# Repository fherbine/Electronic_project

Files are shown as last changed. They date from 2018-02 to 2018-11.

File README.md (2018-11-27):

# Electronic project at 42 - CompassIO project

banner

## Electronic project from 42 school.
During 7 months we had to make a connected compass from scrath.

 - It began in February after we passed a test to be able to register to the Electronic project at school.

 - First we had to write specifications about our project during a month: including user manual, the description of our project and a first Bill of Material. You can access to these specifications [here](https://github.com/fherbine/Electronic_project/blob/master/vomnes_IBoussole_Cahier_des_Charges.pdf).

 - Then we had to make a proof of concept, from march to June. This step has shown our capability to build a final prototype for our project.

POC

- Finally we built our prototype !

Proto

PCB pcb

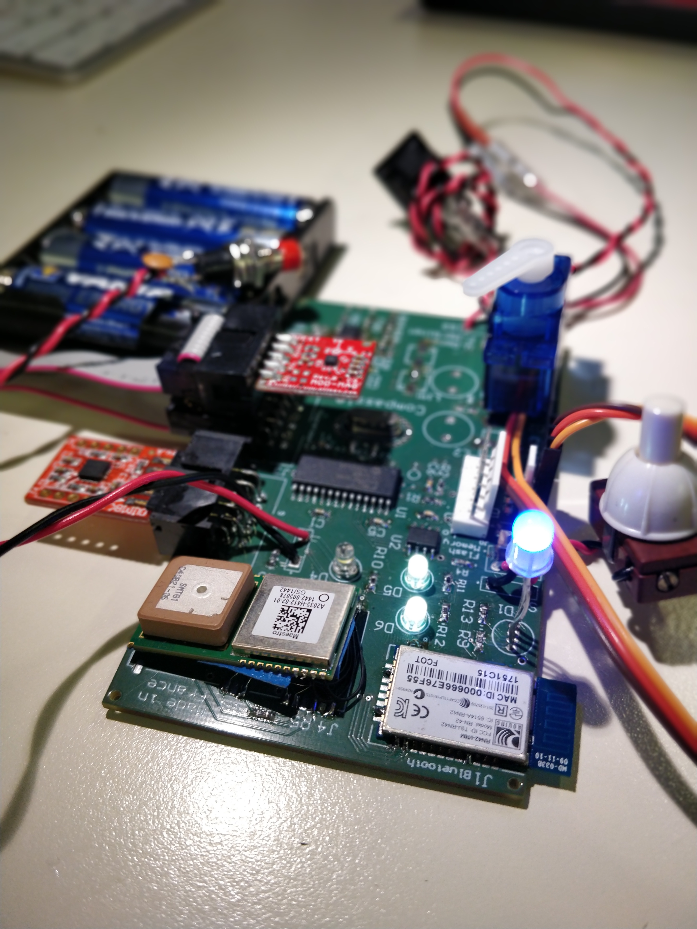
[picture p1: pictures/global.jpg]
Global global


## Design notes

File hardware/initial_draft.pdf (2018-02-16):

Initial schematic draft of the project

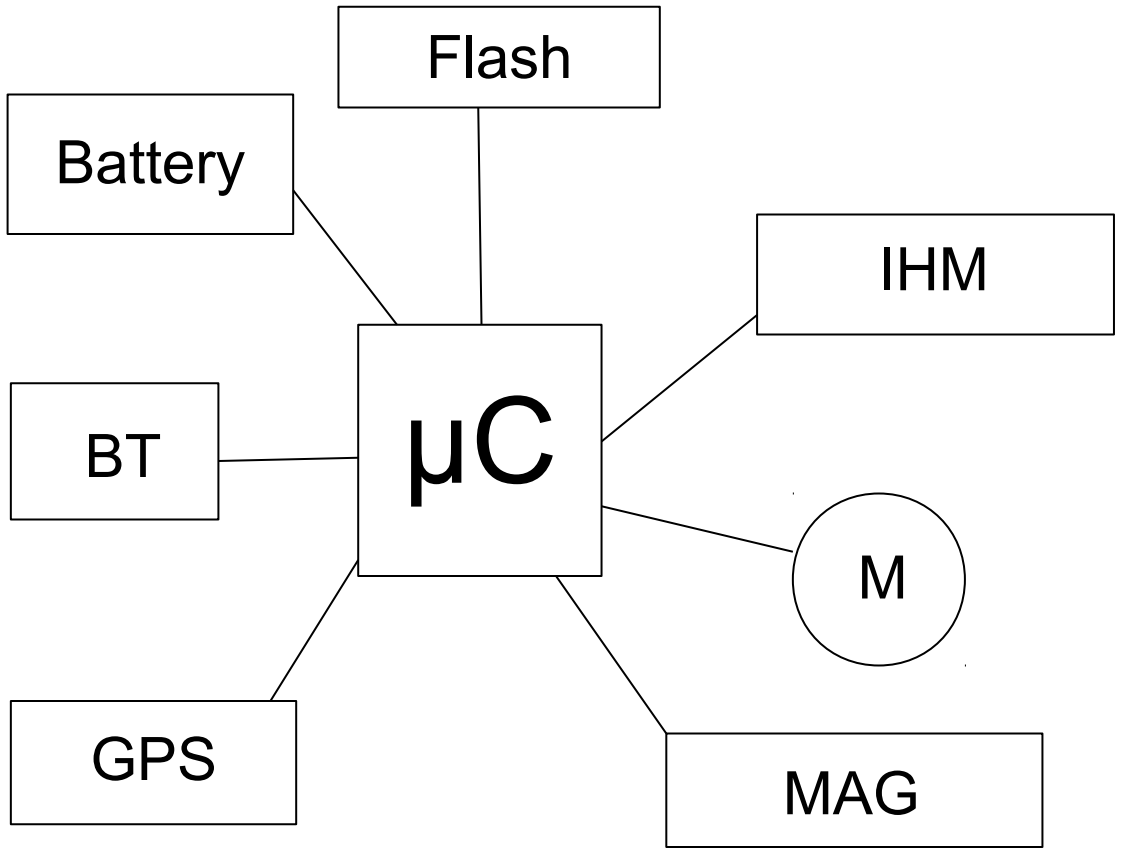
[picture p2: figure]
Flash; Battery; IHM; GPS; MAG

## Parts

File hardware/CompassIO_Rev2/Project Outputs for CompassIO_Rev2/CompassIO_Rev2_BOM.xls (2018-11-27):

Comment | Description | Designator | Fabricant | Fournisseur | Quantity | RefFabricant | RefFournisseur
5-10V | 4xAA | BT1 |  |  | 1
0.1uF | Capacitor | C1, C6, C12 | AVX | Farnell | 3 | 0603YC104KAZ2A | 7569556
0.1µF | Capacitor | C2, C3, C4 | AVX | Farnell | 3 | 0603YC104KAZ2A | 7569556
10µF | Capacitor | C5 | MURATA | Farnell | 1 | GRM188R60J106KE47D | 2494230
100nF | Capacitor | C7 | AVX | Farnell | 1 | 0603YC104KAZ2A | 7569556
22uF | Capacitor | C8 | MURATA | Farnell | 1 | GRM188R61A226ME15D | 2666496
8.2nF | Capacitor | C9 | MULTICOMP | Farnell | 1 | MC0603B822K500CT | 1759101
1.2nF | Capacitor | C10 | Walsin | Farnell | 1 | 0603B122K500CT | 2524822
25pF | Capacitor | C11 | WALSIN | Farnell | 1 | 0603N250J500CT | 2524884
47uF | Capacitor | C13, C14 | MURATA | Farnell | 2 | GRM21BR60J476ME15L | 2362109
LED3 | Typical BLUE SiC LED | D1, D2, D3 | ROHM | Farnell | 3 | SMLE13WBC8W1 | 2762565
LED0 | Typical INFRARED GaAs LED | D4, D6 | KINGBRIGHT | Farnell | 2 | KPH-1608SGC, KPT-1608LVVBC-D | 2426215, 2610410
LED0 | Typical INFRARED GaAs LED | D5 | KINGBRIGHT | Farnell | 1 | KP-2012EC | 8529949
SS24FL | Schottky Rectifier | D7 | ON SEMICONDUCTOR | Farnell | 1 | SS24FL | 2822566
Program / Debug | Program / Debug | J0 | Molex | Farnell | 1 | 22-27-2061 | 9731172
jumper | Jumper | J1, J7 |  |  | 2
RN42 | Bluetooth Module | J2 | Microchip | Farnell | 1 | RN42-I/RM | 2143310
DEBUG1 | Debug interface | J3, J6 |  |  | 2
MAG3110 Breakout | MAG3110 Breakout | J4 | AMP - TE Connectvity | Farnell | 1 | 5103310-1 | 2452436
A2035-H | GPS Module | J5 | MAESTRO WIRELESS SOLUTIONS | Farnell | 1 | A2035H | 2281693
10uH | Inductor | L1 | BOURNS | Farnell | 1 | SRN8040-100M | 2061669
SG90 | Servo motor | M1 | Molex | Farnell | 1 | 22-27-2031 | 9731156
10K | Resistor | R1, R2, R4, R5, R8 | PANASONIC ELECTRONIC COMPONENTS | Farnell | 5 | ERA3ARW103V | 1688472
1K | Resistor | R3 | PANASONIC ELECTRONIC COMPONENTS | Farnell | 1 | ERA3ARB102V | 1717570
2.4K | Resistor | R6, R7 | VISHAY | Farnell | 2 | CRCW06032K40FKEA | 1469766
100 | Resistor | R9, R10, R11, R12, R13 | VISHAY | Farnell | 5 | CRCW0603100RJNEA | 2616742
330 | Resistor | R14 | PANASONIC ELECTRONIC COMPONENTS | Farnell | 1 | ERJ3GEYJ331V | 2059588
174K | Resistor | R15 | VISHAY | Farnell | 1 | CRCW0603174KFKEA | 2138522
133K | Resistor | R16 | MULTICOMP | Farnell | 1 | MCWR06X1333FTL | 2694713
44.2K | Resistor | R17 | VISHAY | Farnell | 1 | CRCW060344K2FKEA | 2138466
10.2K | Resistor | R18 | PANASONIC ELECTRONIC COMPONENTS | Farnell | 1 | ERJ3EKF1022V | 2059407
3.24K | Resistor | R19 | VISHAY | Farnell | 1 | CRCW06033K24FKEA | 1652877
SW-PB | Switch | S1, S2 | ALCOSWITCH - TE CONNECTIVITY | Farnell | 2 | 1437566-3 | 2468741
SW-SPST | Single-Pole, Single-Throw Switch | S3, S4 | Arcolectric | Farnell | 2 | H8600VBAAA | 151133
PIC32MX250F128B | Microcontrolleur | U1 | Microchip | Farnell | 1 | PIC32MX250F128B-I/SO | 2097772
LE25U40CMD | Flash memory | U2 | On Semiconductor | Farnell | 1 | LE25U40CMDTWG | 2627898
TPS54231D | Buck SD 3.3V | U3 | Texas Instruments | Farnell | 1 | TPS54231D | 2854681

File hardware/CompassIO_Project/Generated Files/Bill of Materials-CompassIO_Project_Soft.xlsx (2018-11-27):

Comment | Description | Designator | Fabricant | Footprint | Fournisseur | Library Reference | Quantity | RefFabricant | RefFournisseur
SG90 | Servo motor | MP1 | MCmall |  | Amazon | SG90 | 1 | SG90 180 Mini Servo
MOSFET-2N7002 | N-Channel MOSFET | Q1 | ON SEMICONDUCTOR | E3 | Farnell | MOSFET-N | 1 | 2N7002 | 2323152
RN42 | Bluetooth Module | U1 | Microchip |  | Farnell | RN42 | 1 | RN42-I/RM | 2143310
MOD-MPU9150 | 9-Axis | U2 | Olimex - InvenSense |  | Olimex | MOD-MPU9150 | 1 | MOD-MPU9150 | MOD-MPU9150
A2035-H | GPS Module | U3 | MAESTRO WIRELESS SOLUTIONS |  | Farnell | A2035-H | 1 | A2035H | 2281693
LE25U40CMD | Flash memory | U4 | On Semiconductor |  | Farnell | LE25U40CMD | 1 | LE25U40CMDTWG | 2627898

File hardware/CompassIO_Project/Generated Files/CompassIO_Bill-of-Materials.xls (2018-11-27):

BILL OF MATERIALS
Projet : |  | CompassIO.PrjPcb |  |  | Toutes résistances 1% sauf indication contraire
Date creation : |  | 26/04/2018 |  |  | Tous condensateurs X5R 6.3V minimum sauf indication contraire
Date impression : |  | 2018-04-26 | 20:03:22 |  | Condensateurs <= 100nF : C0G ou NP0 préférables
Quantity | LogicalDesignator | Comment | Footprint | Description | Fabricant | RefFabricant | Fournisseur | RefFournisseur
2 | D1, D3 | Green LED | LED-0 | Connection Status, Blinky LED
1 | D2 | Red LED | LED-0 | Activity
2 | R1, R2 | 470 | AXIAL-0.3 | Resistor
1 | R3 | 10K | AXIAL-0.3 | Resistor
1 | R4 | 1K | AXIAL-0.3 | Resistor
2 | R5, R6 | 5K | AXIAL-0.3 | Resistor
3 | S1, S3, S5 | Single-Pole, Single-Throw Switch | SPST-2 | Button Discovery, GPS Firmware, Disable write protect
3 | S2, S4, S6 | Switch | SPST-2 | Factory reset, Reset, Suspend communication
1 | U1 | RN42 |  | Bluetooth Module | Microchip | RN42-I/RM | Farnell | 2143310
1 | U2 | MOD-MPU9150 |  | 9-Axis | Olimex - InvenSense | MOD-MPU9150 | Olimex | MOD-MPU9150
1 | U3 | A2035-H |  | GPS Module | MAESTRO WIRELESS SOLUTIONS | A2035H | Farnell | 2281693
1 | U4 | LE25U40CMD |  | Flash memory | On Semiconductor | LE25U40CMDTWG | Farnell | 2627898

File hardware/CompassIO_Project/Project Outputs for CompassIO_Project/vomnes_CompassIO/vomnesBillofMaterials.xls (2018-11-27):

BILL OF MATERIALS
Projet : |  | CompassIO_Project.PrjPcb
Date creation : |  | 28/01/2015 | 17:45:48
Date impression : |  | 2018-07-02 | 19:32:13
Quantity | LogicalDesignator | Comment | Footprint | Description | Fabricant | RefFabricant | Fournisseur | RefFournisseur | Precision | #Column Name Error:Notes
2 | C11, C12 | Cin | WE-865080542005 | Polarized Capacitor (Radial) | WURTH ELEKTRONIK | 865080542005 | Farnell | 2466314 | Cap Pol1
1 | C16 | Cout | SMT-HA-V-D | Polarized Capacitor (Radial) | PANASONIC ELECTRONIC COMPONENTS | EEEHA1A101WP | Farnell | 1973294 | Cap Pol1
1 | D1 | L-154A4SUREQBFZGEW | L-154A4SUREQBFZGEW | LED RGB | Kingbright | L-154A4SUREQBFZGEW | Farnell | 2290375 | L-154A4SUREQBFZGEW
1 | D2 | MBRS130LT3 | SMB-403A-03-J | Schottky Rectifier | ON SEMICONDUCTOR | MBRS130LT3G | Farnell | 9556931 | Diode 10TQ035
1 | D3 | B240A | SMA-B2XX/A | Schottky Rectifier | DIODES INC. | B240A-13-F | Farnell | 1843669 | Diode 10TQ035
3 | D4, D5, D6 | LED3 | LED2.5 | Typical BLUE SiC LED | MULTICOMP | MCL034SWC-WH1 | Farnell | 1581176 | LED3
1 | J0 | Program / Debug | C-Grid III X6 | Program / Debug | Molex | 90120-0126 | Farnell | 2313717 | ICSP
2 | J2, J3 | MOD Connector | UEXT_MALE x10 | UEXT | AMP - TE Connectivy | 5103310-1 | Farnell | 2452436 | MOD-MPU9150
3 | L1, L2, L3 | 10uH | RLB Series | Inductor | BOURNS | RLB0712-100KL | Farnell | 2434811 | Inductor
1 | M1 | SG90 Connector | C-Grid III x3 | Servo motor Connector | Molex | 22-27-2031 | Farnell | 9731156 | SG90
1 | Q1 | MOSFET-2N7002 | 2N7002 | N-Channel MOSFET | ON SEMICONDUCTOR | 2N7002 | Farnell | 9845313 | MOSFET-N
1 | Q2 | IRF7807 | SO-8 | MOSFET-8 | INFINEON | IRF7807VTRPBF | Farnell | 2839485 | IRF7807
2 | S3, S4 | SW-SPST | SPST-2 | Single-Pole, Single-Throw Switch | Arcolectric | H8600VBAAA | Farnell | 151133 | SW-SPST
1 | U1 | PIC32MX250F128B | PIC32MX250F128/SO | Microcontrolleur | Microchip | PIC32MX250F128B-I/SO | Farnell | 2097772 | PIC32MX250F128B
1 | U3 | LM3488 | S-PDSO-G8 | SEPIC 5V | Texas Instruments | LM3488MMX/NOPB | Farnell | 2769264 | LM3488
1 | U4 | TPS54231D | R-PDSO-G8 | Buck SD 3.3V | Texas Instruments | TPS54231D | Farnell | 1755637 | TPS54231D
1 | Y1 | 8MHz | 9B-8.000MAAJ-B | Crystal Oscillator | TXC | 9B-8.000MAAJ-B | Farnell | 1842268 | XTAL
2 | J3 | MAG3110 |  | Magnetometer | Olimex | MAG3110 | Olimex | MOD-MAG

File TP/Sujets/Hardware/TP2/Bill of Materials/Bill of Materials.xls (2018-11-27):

BILL OF MATERIALS
Projet : |  | TP2.PrjPcb |  |  | Toutes résistances 1% sauf indication contraire
Date creation : |  | 28/01/2015 | 17:28:42 |  | Tous condensateurs X5R 6.3V minimum sauf indication contraire
Date impression : |  | 2015-01-28 | 17:28:44 |  | Condensateurs <= 100nF : C0G ou NP0 préférables
Quantity | LogicalDesignator | Comment | Footprint | Description | Fabricant | RefFabricant | Fournisseur | RefFournisseur | Precision | #Column Name Error:Notes
7 | C1, C2, C3, C4, C5, C6, C15 | 100nF | CAPC1608N | Capacitor |  |  |  |  | 50V X5R
2 | C7, C8 | 20pF | CAPC1005N | Capacitor |  |  |  |  | 50V X5R
4 | C9, C11, C12, C13 | 10uF | CAPC2012N | Capacitor | TDK | C2012X5R0J106M/1.25 | Farnell | 2309029 | 6,3V X5R
2 | C10, C14 | 1uF | CAPC1608N | Capacitor |  |  |  |  | 6,3V X5R
5 | D1, D1, D1, D1, D4 | Green LED | LED 0805 | Typical INFRARED GaAs LED | KINGBRIGHT | KPT-2012SGC | Farnell | 2099239
2 | D2, D3 | GF1A | SMA/DO-214AC_21 | Default Diode | VISHAY | GF1A-E3/67A | Farnell | 9549560
1 | FB1 | 600r | INDC1608AN | Inductor | Wurth | 742792651 | Farnell | 1635706
1 | J1 | Program / Debug | MOLEX 6P 1.25 CMS |  | Molex | 53398-0671 | Farnell | 1125368
1 | P1 | 12V Main | PHOENIX_1985195 | Header, 2-Pin | PHOENIX CONTACT | PTSA 1.5/2-3,5-Z | Farnell | 1792769
1 | P2 | 12V Battery | PHOENIX_1985195 | Header, 2-Pin | PHOENIX CONTACT | PTSA 1.5/2-3,5-Z | Farnell | 1792769
1 | R1 | 1K | PDB181-K415K-102A2 | Potentiometer | BOURNS | PDB181-K415K-102A2 | Farnell | 1823540
4 | R2 | 330r | RESC1608N | Resistor |  |  |  |  | 1%
1 | R3 | 4.7k | RESC1608N | Resistor |  |  |  |  | 1%
1 | R4 | 470r | RESC1608N | Resistor |  |  |  |  | 1%
1 | U1 | PIC32MX764F128H-I/PT | QFP50P1200X1200X120-64 | PIC32MX764F128H | Microchip | PIC32MX764F128H-I/PT | Farnell | 1971889
1 | U2 | AP1117 | TD03B_N | 1A LDO, 18V input, DPAK | DIODES INC | AP1117D33G-13 | Farnell | 1825285
1 | Y1 | 8MHz | XTAL139X50X45 | Crystal Oscillator | FOX ELECTRONICS | FOXSDLF/080-20 | Farnell | 2063972

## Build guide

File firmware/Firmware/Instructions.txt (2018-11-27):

Le TP se déroule en étapes, à faire valider à chaque fois :

0/ Boot from scratch

Créer un nouveau projet et y ajouter un nouveau .h contenant des typedefs pour :
- u8, u16 et u32
- s8, s16 et s32

1/ Commande de la LED par le bouton (a.k.a Hello World!)

Une pression sur le bouton allume la led
Une autre pression sur le bouton éteint la led

2/ Clignotement de la LED

La led clignotte au rythme d'un changement d'état par seconde (0.5Hz, 1s on/1s off).
Une pression sur le bouton multiplie par deux le rythme de clignotement. Arrivé à 8Hz, une pression sur le bouton remet le rythme à 0.5Hz.

La "séquence" sera donc : 0.5Hz, 1Hz, 2Hz, 4Hz, 8hZ, 0.5Hz, 1Hz, ...

Vous devez utiliser un timer pour régler la vitesse de clignotement

3/ Utilisation des interruptions

Votre code doit maintenant être "non bloquant", votre main loop ne doit contenir qu'un statement: clear watchdog
Le clignotement ainsi que la gestion du bouton doivent être fait dans une ISR.

4/ DIM de la LED (a.k.a pour-les-vrais-qui-en-ont-dans-le-slip-ou-le-string)

Votre code fait toujours la même chose, mais sur un appui long (>2s) la led passe en mode DIM, en 5s son intensité passe de 0 à 100% puis de 100% à 0% (et ainsi de suite)

Pour cela vous coderez en firmware un PWM sur la GPIO qui contrôle la LED.

5/ Ca y est, vous savez tout faire, elle est pas belle la vie ?

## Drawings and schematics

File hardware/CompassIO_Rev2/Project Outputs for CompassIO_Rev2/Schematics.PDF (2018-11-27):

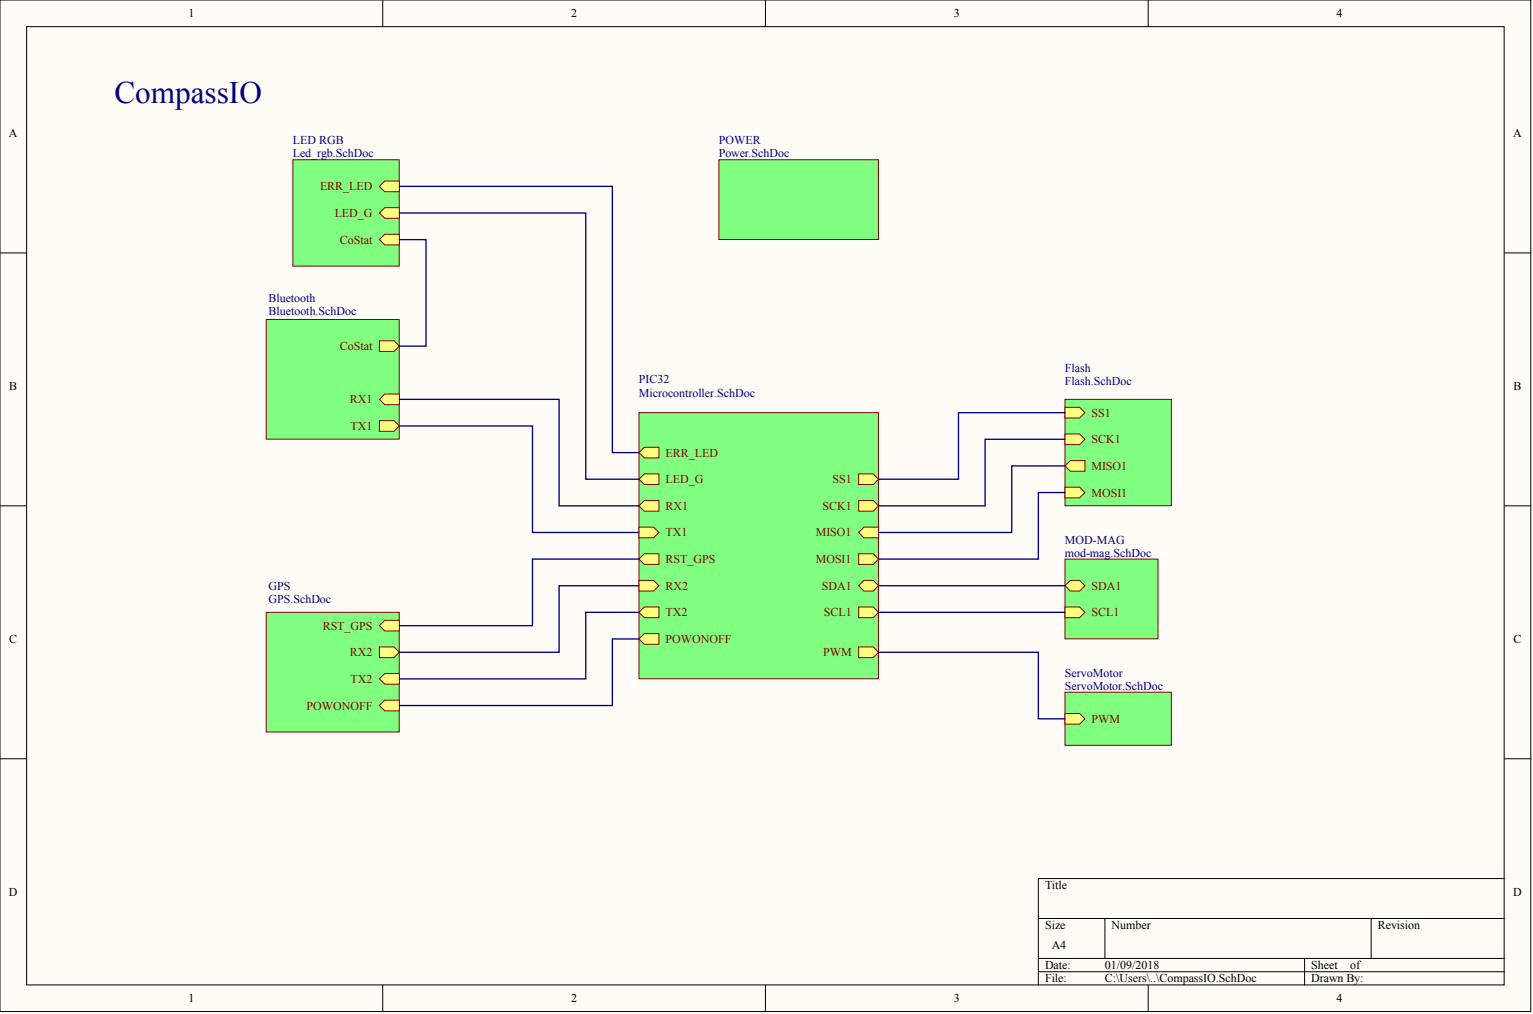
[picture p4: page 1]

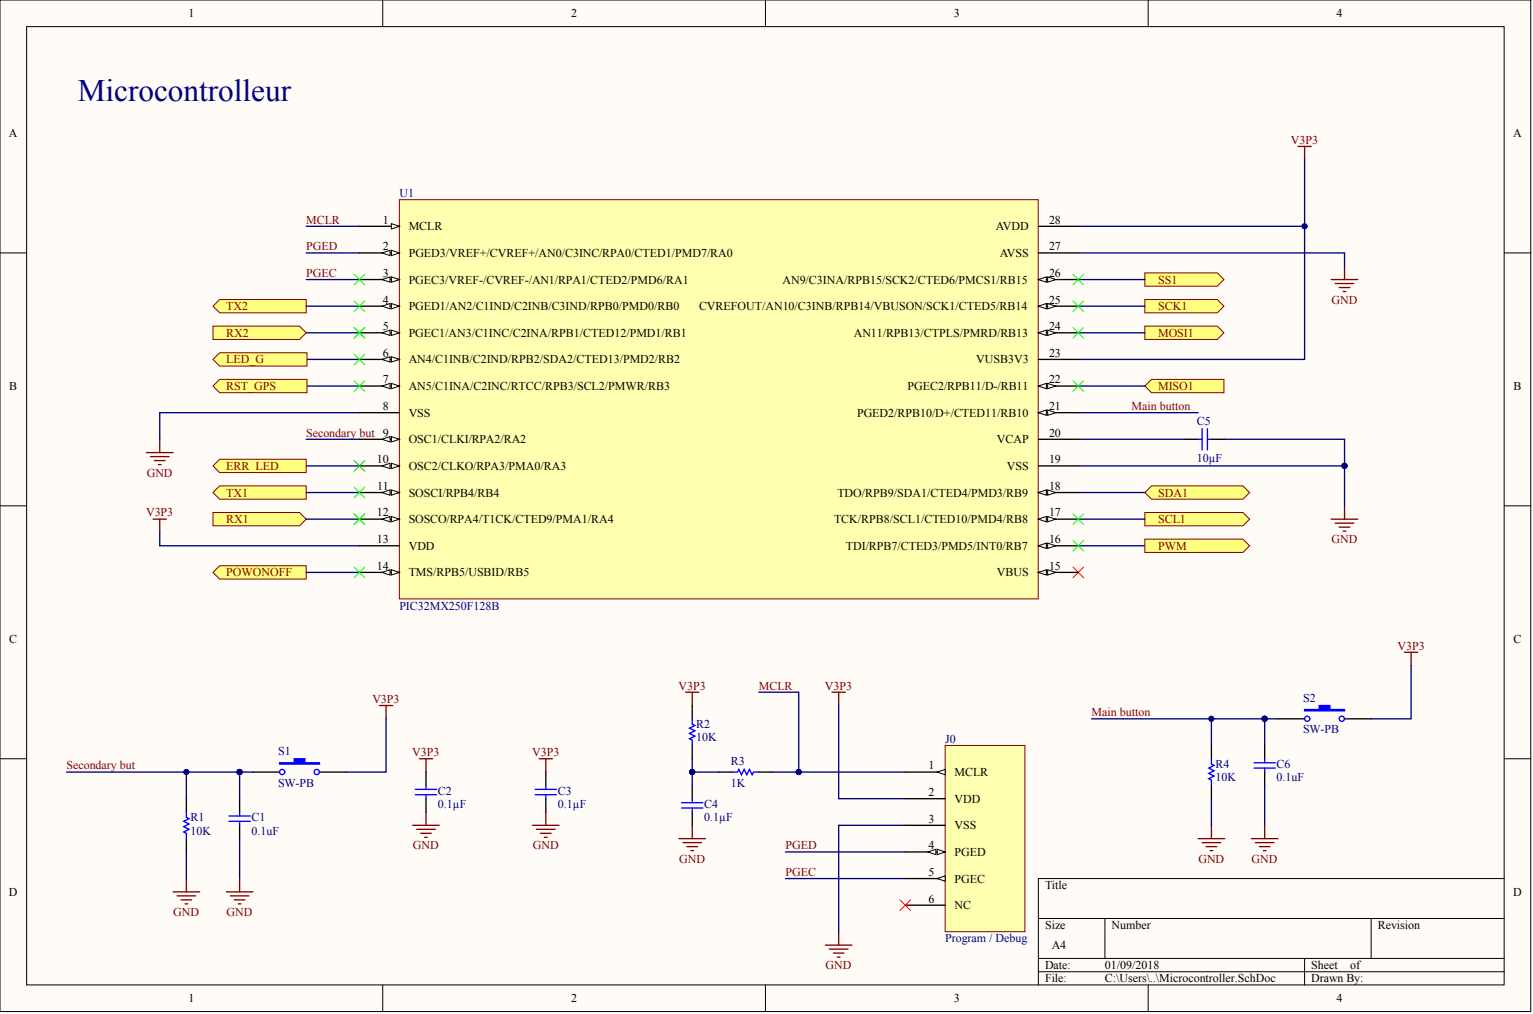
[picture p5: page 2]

Secondary but | | OSC1/CLKI/RPA2/RA2 9

OSC2/CLKO/RPA3/PMA0/RA3 10 | 10µF

SOSCI/RPB4/RB4 11 | | SDA1

VDD 2

VSS 3

PGED 4 PGEC 5

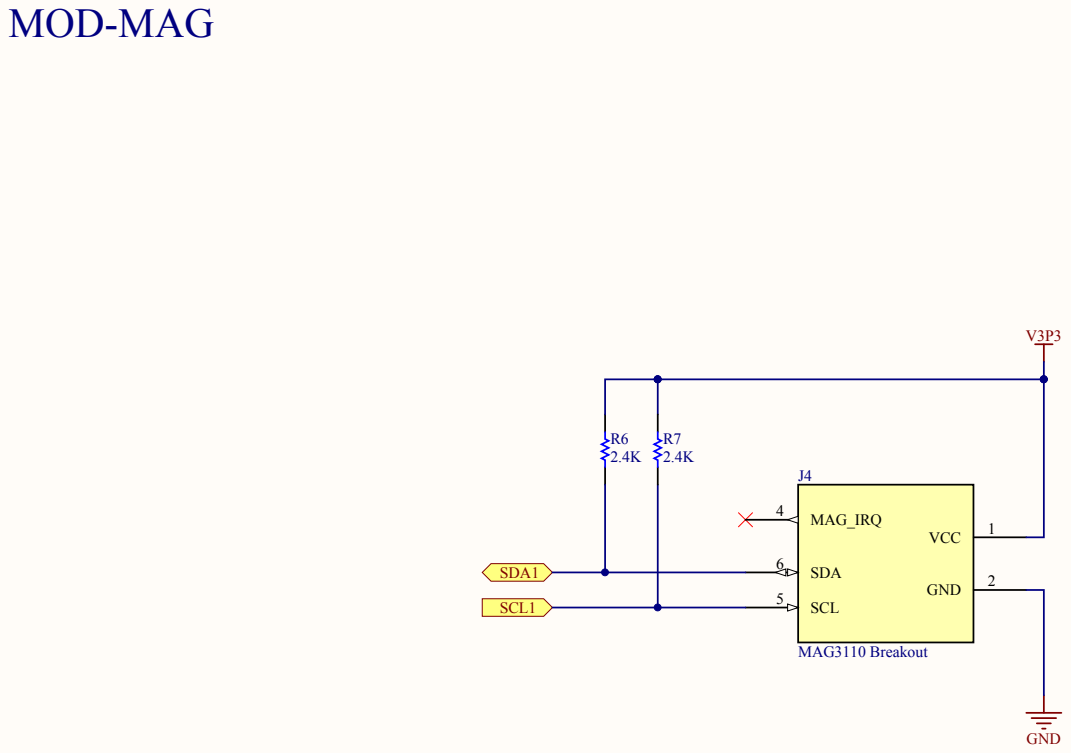
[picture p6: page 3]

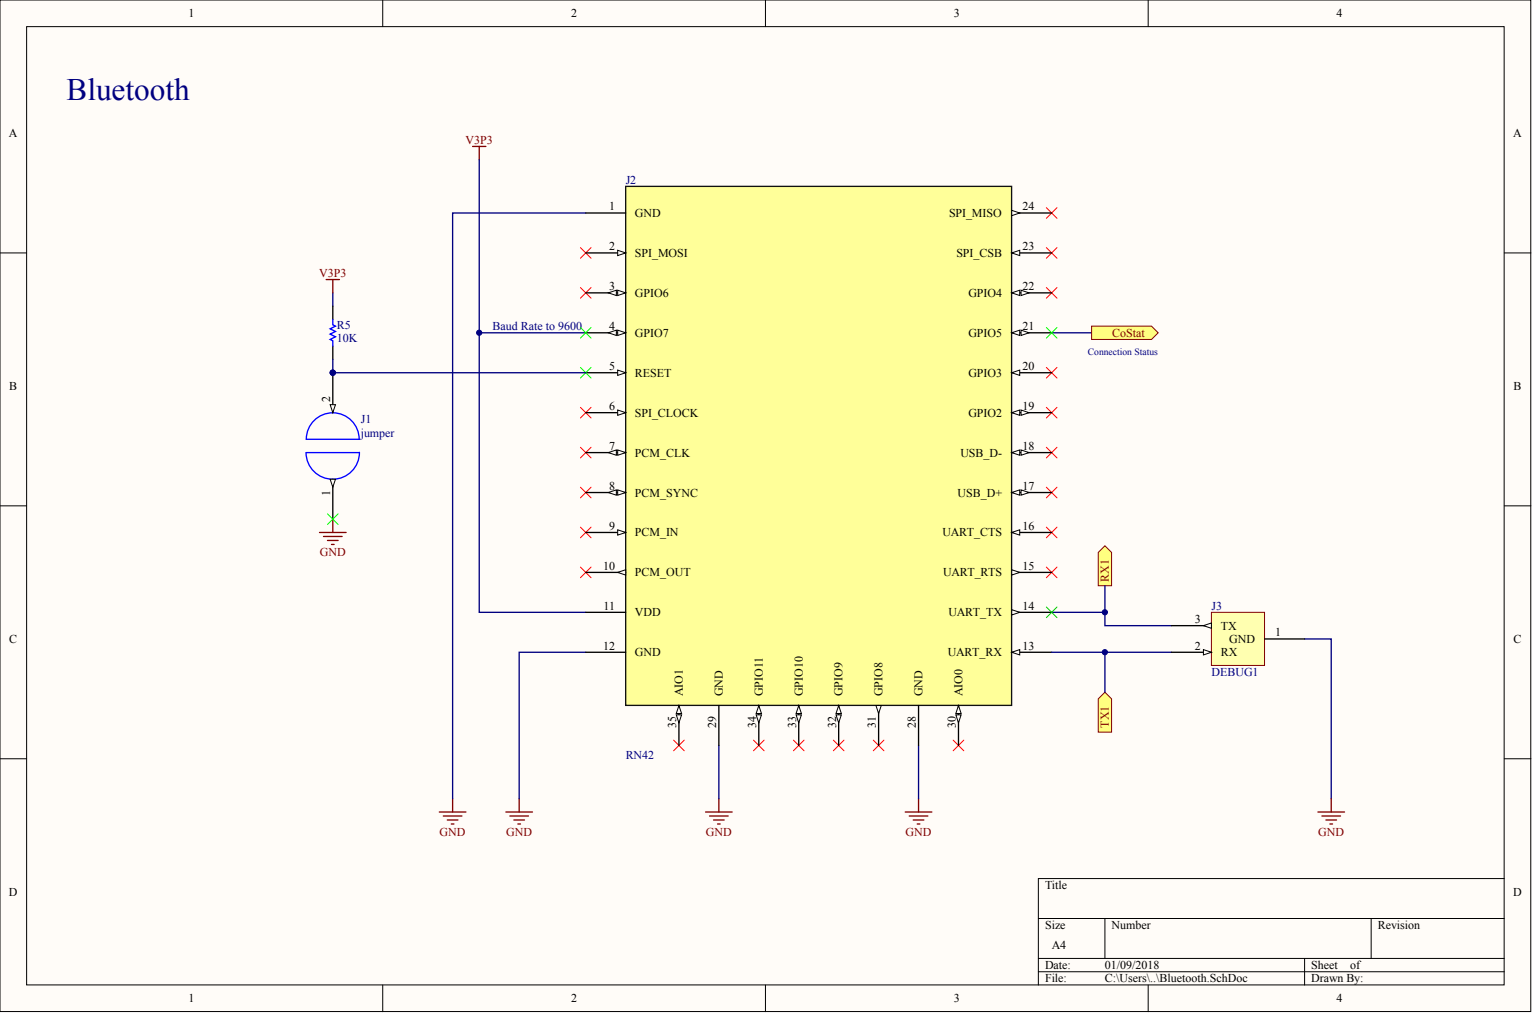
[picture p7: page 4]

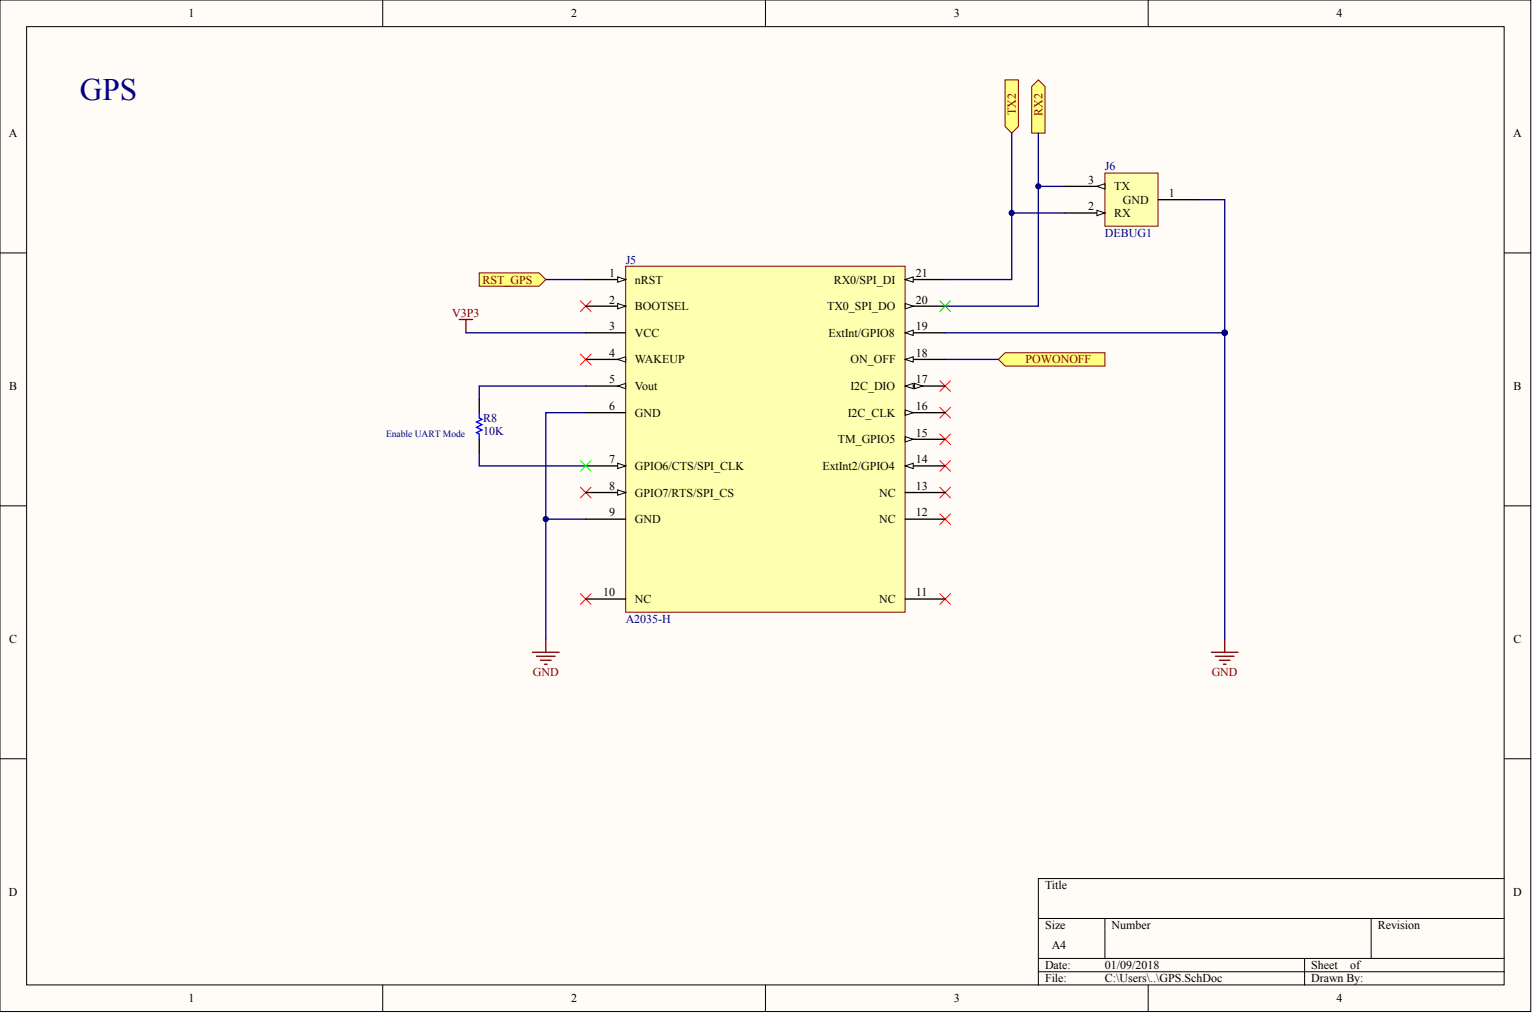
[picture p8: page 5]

GND 6

GPIO7/RTS/SPI_CS 8

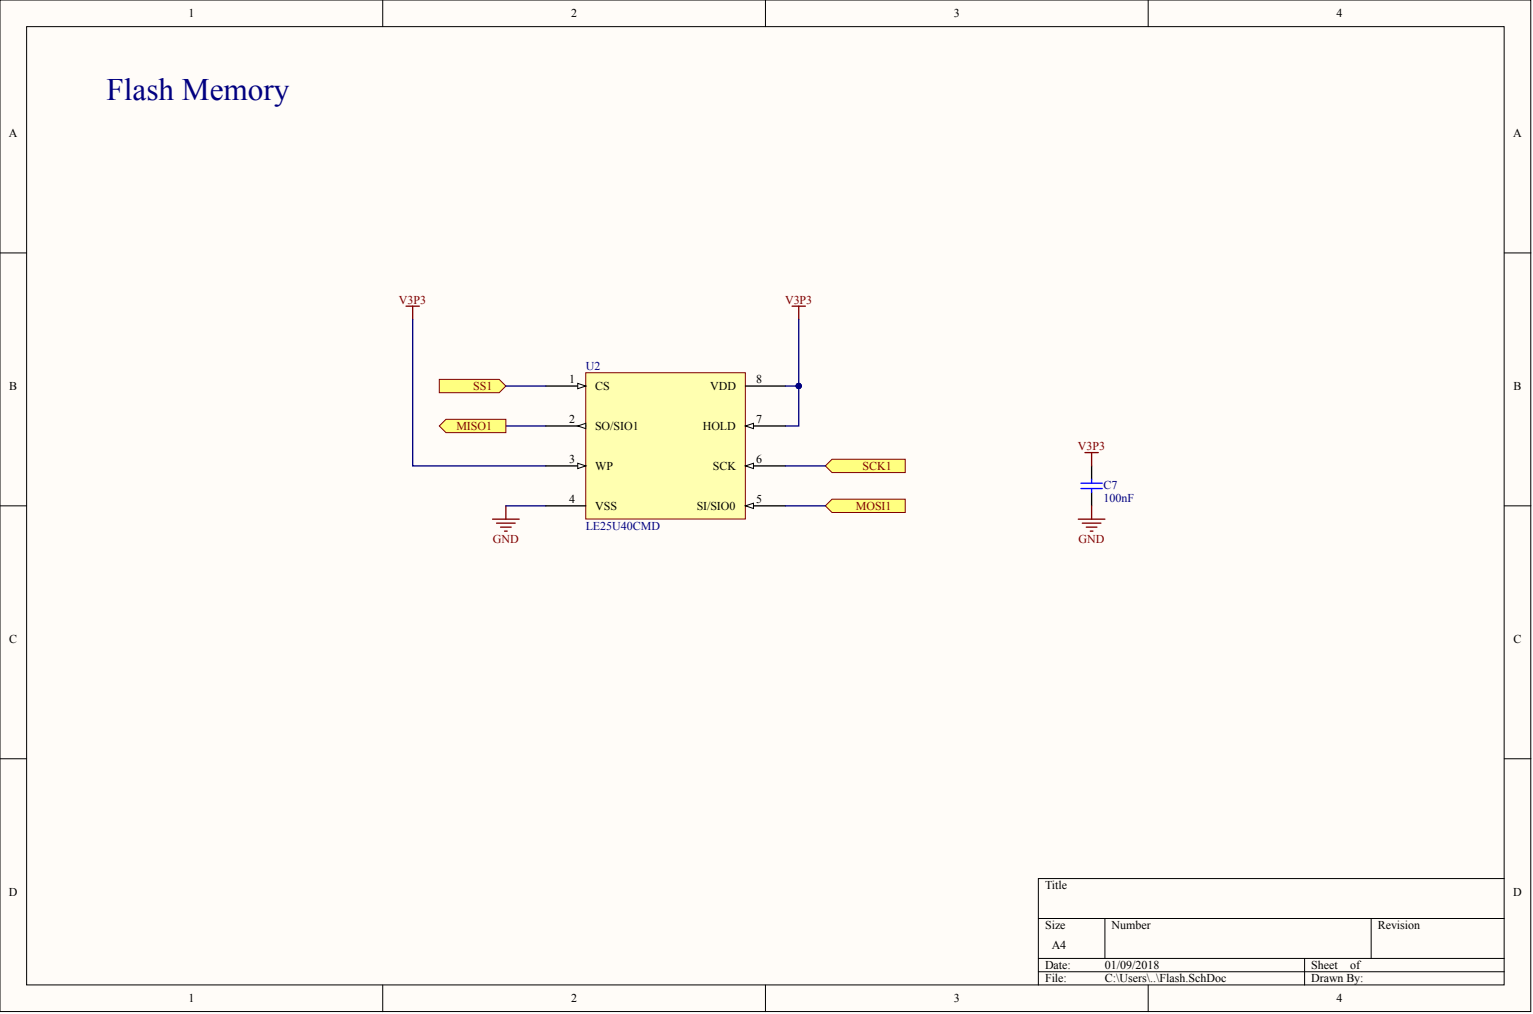
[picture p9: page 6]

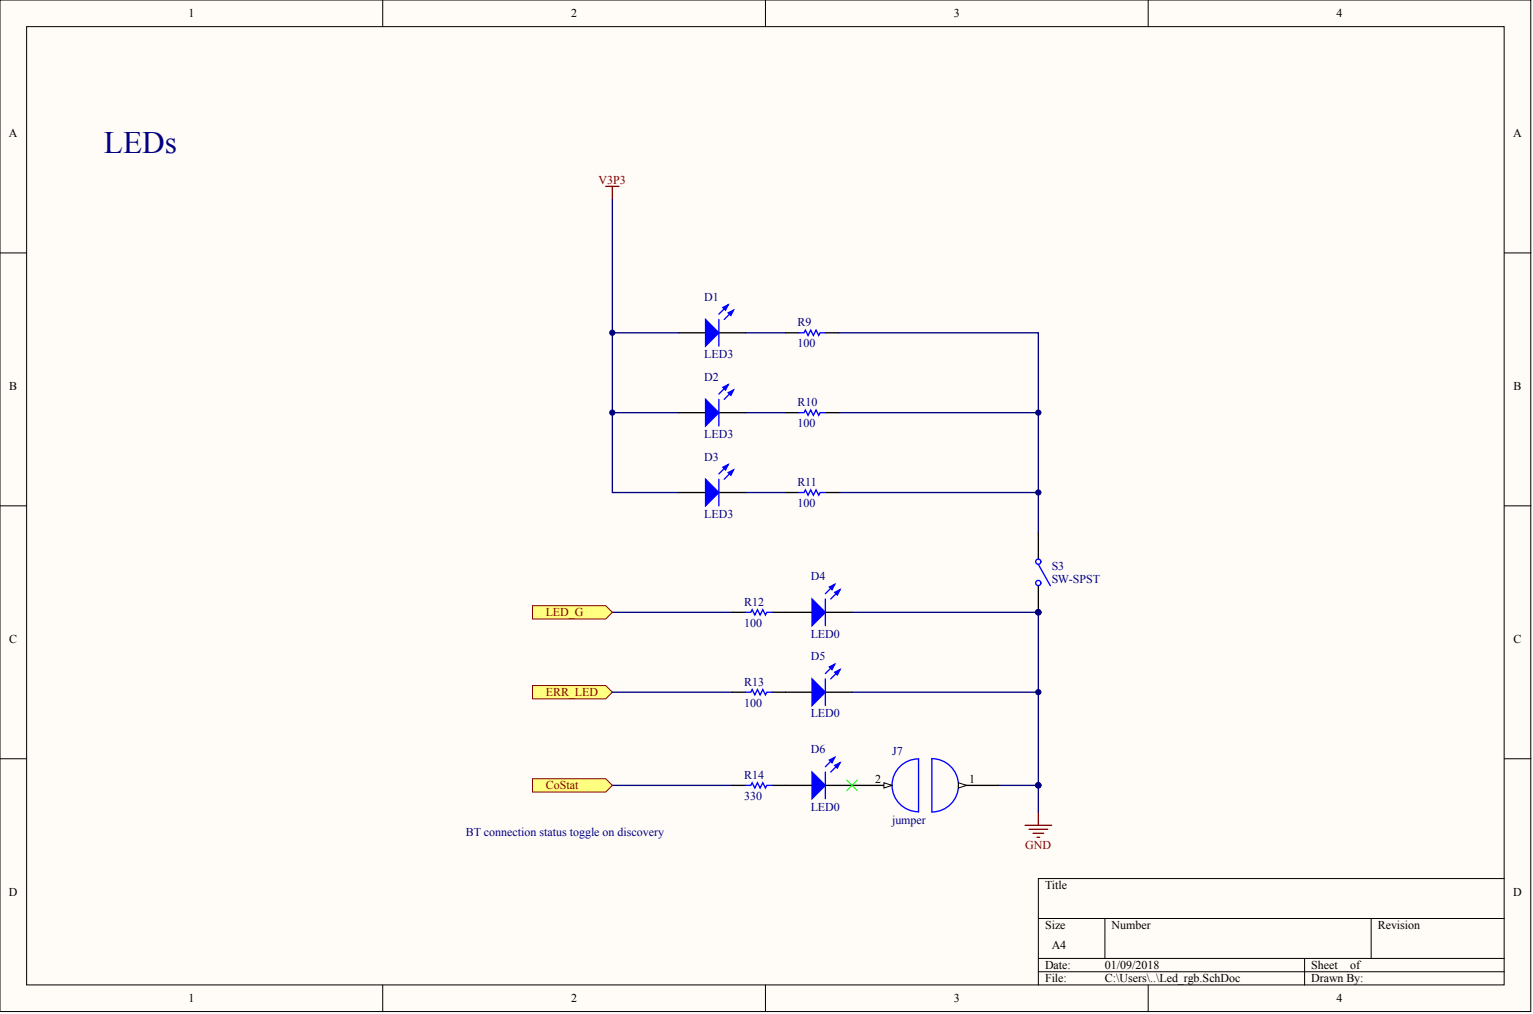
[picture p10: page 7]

BT connection status toggle on discovery

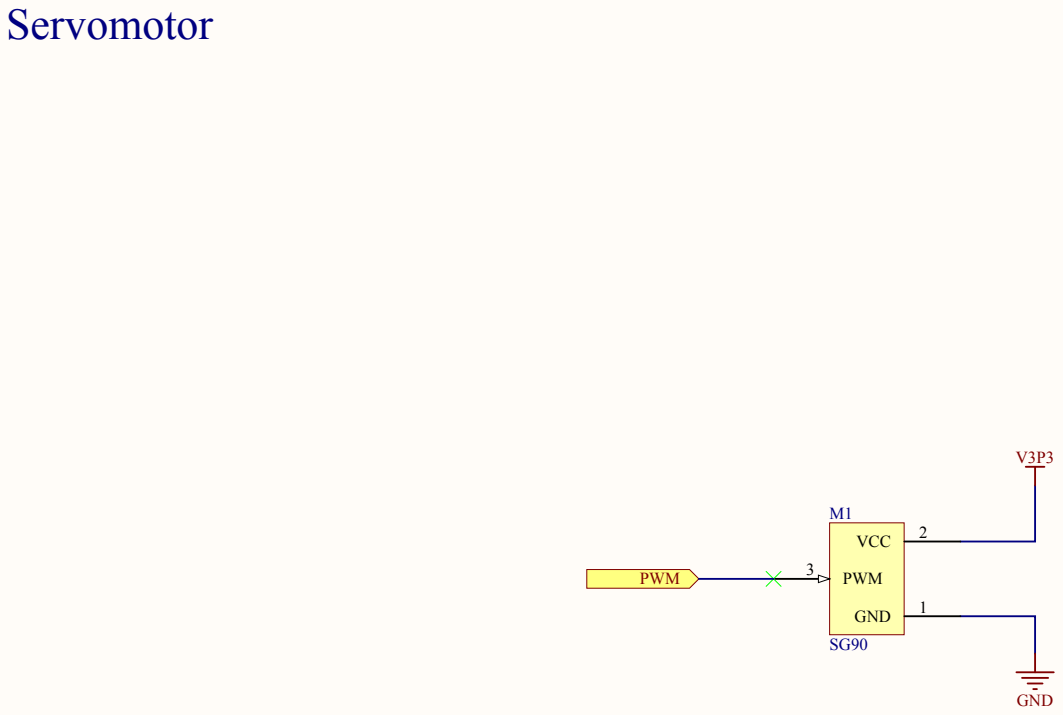
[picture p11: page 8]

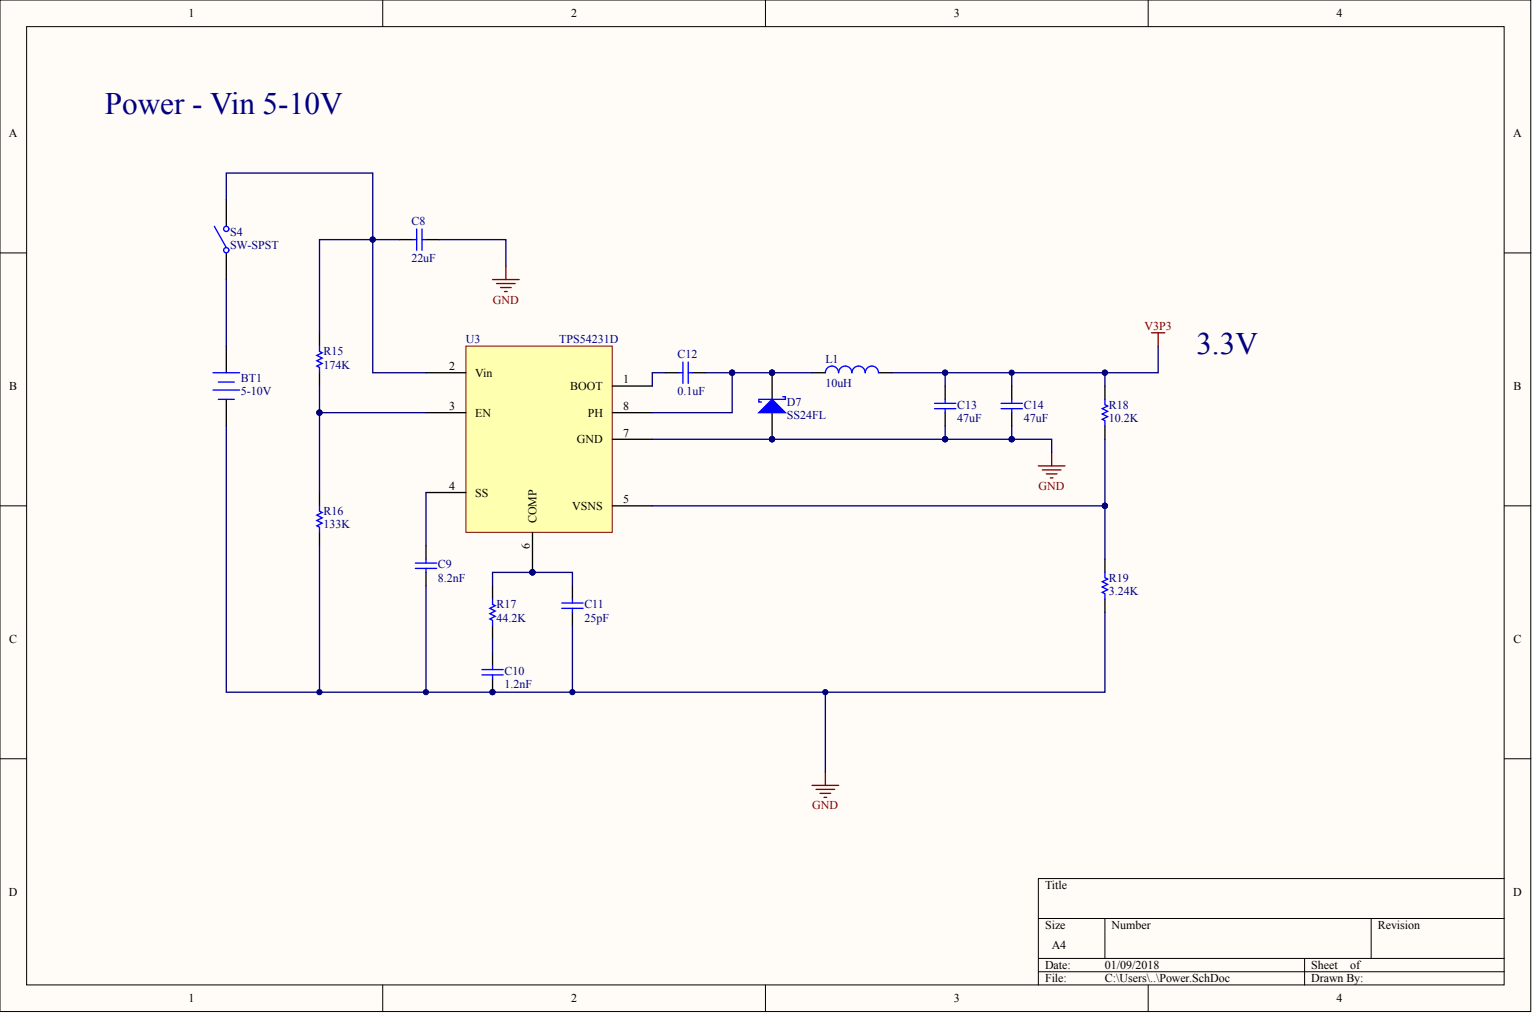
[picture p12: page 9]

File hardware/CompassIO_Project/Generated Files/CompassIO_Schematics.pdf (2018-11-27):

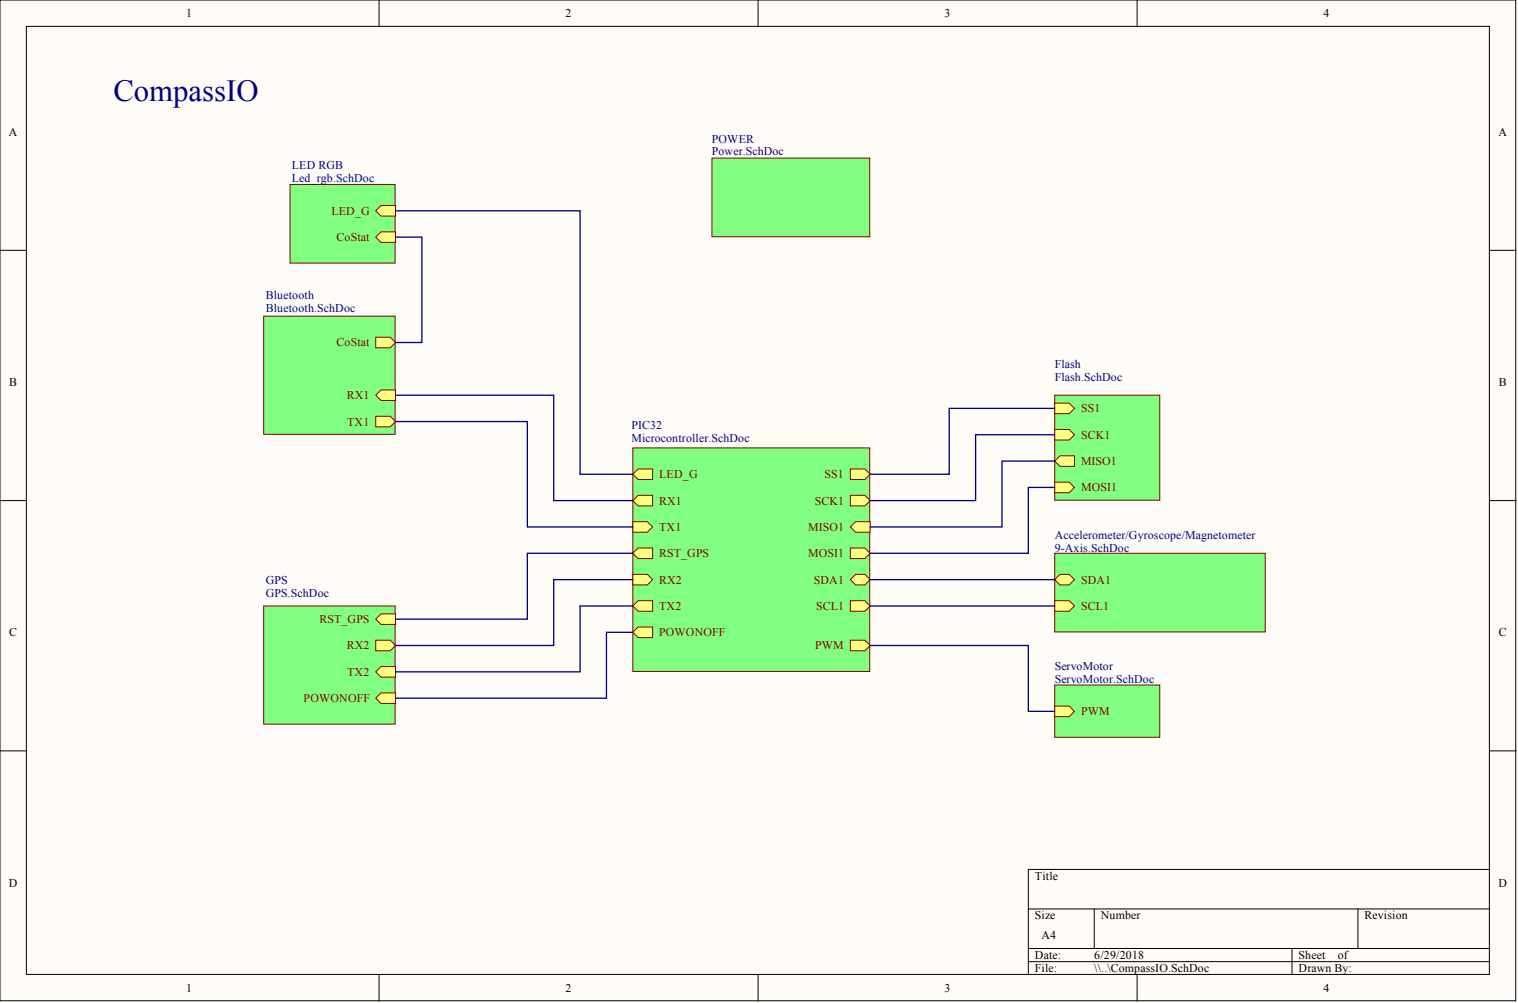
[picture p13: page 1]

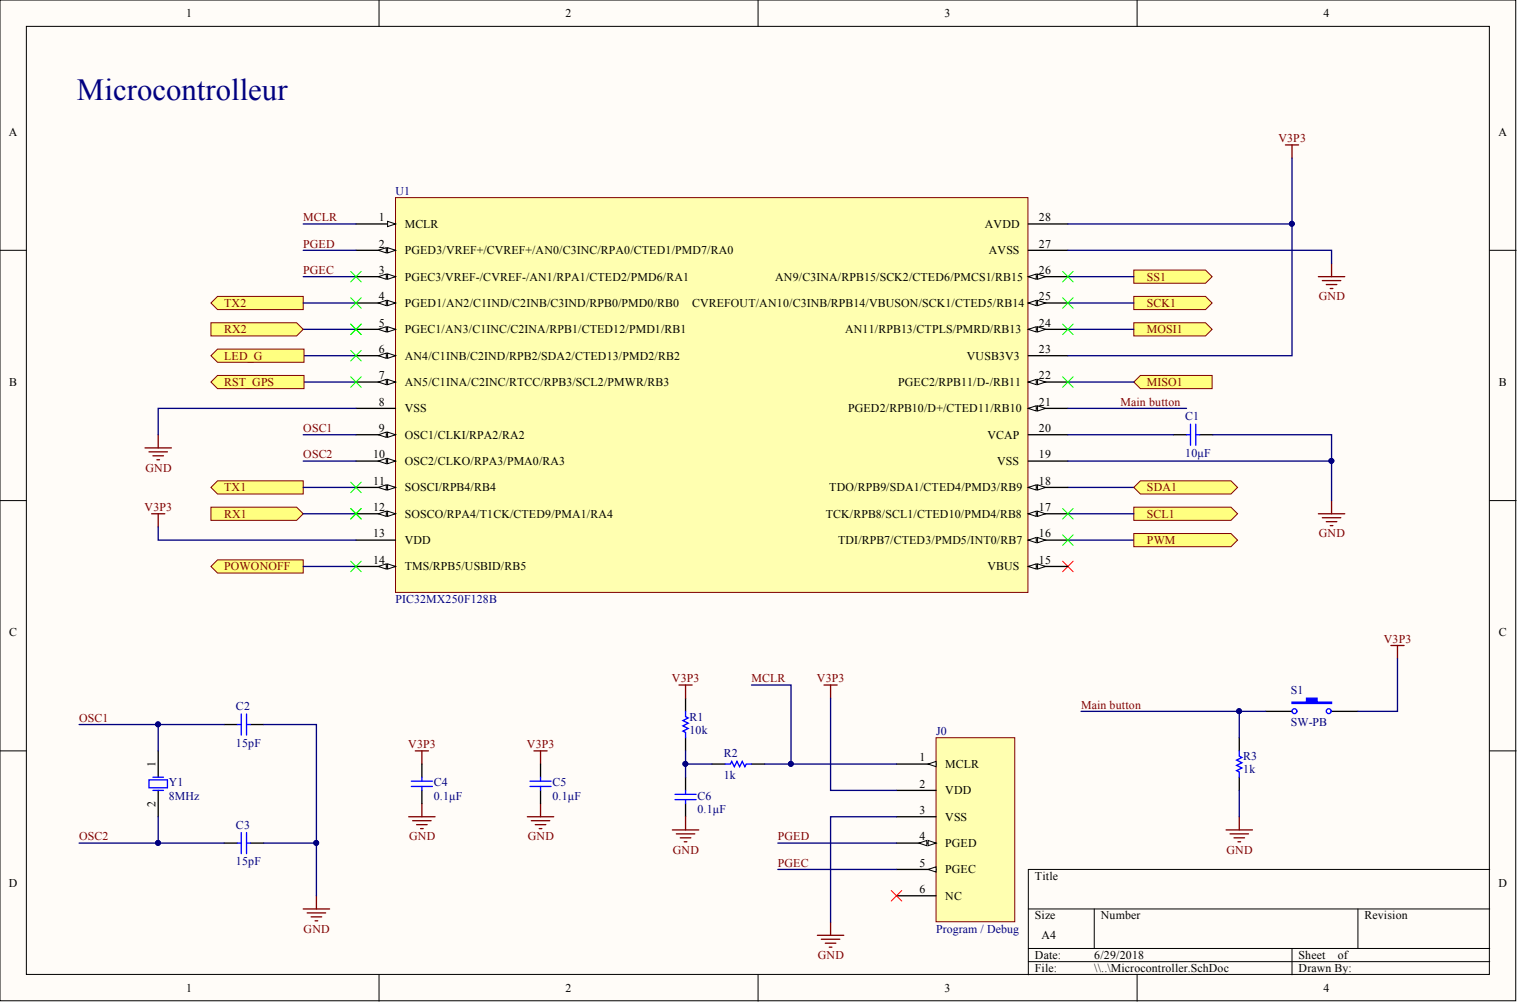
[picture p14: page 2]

OSC1 | | OSC1/CLKI/RPA2/RA2 9

OSC2/CLKO/RPA3/PMA0/RA3 10 SOSCI/RPB4/RB4 11 SOSCO/RPA4/T1CK/CTED9/PMA1/RA4 12 VDD 13 | 10μF

SDA1

VDD 2

VSS 3

PGED 4 PGEC 5 NC 6

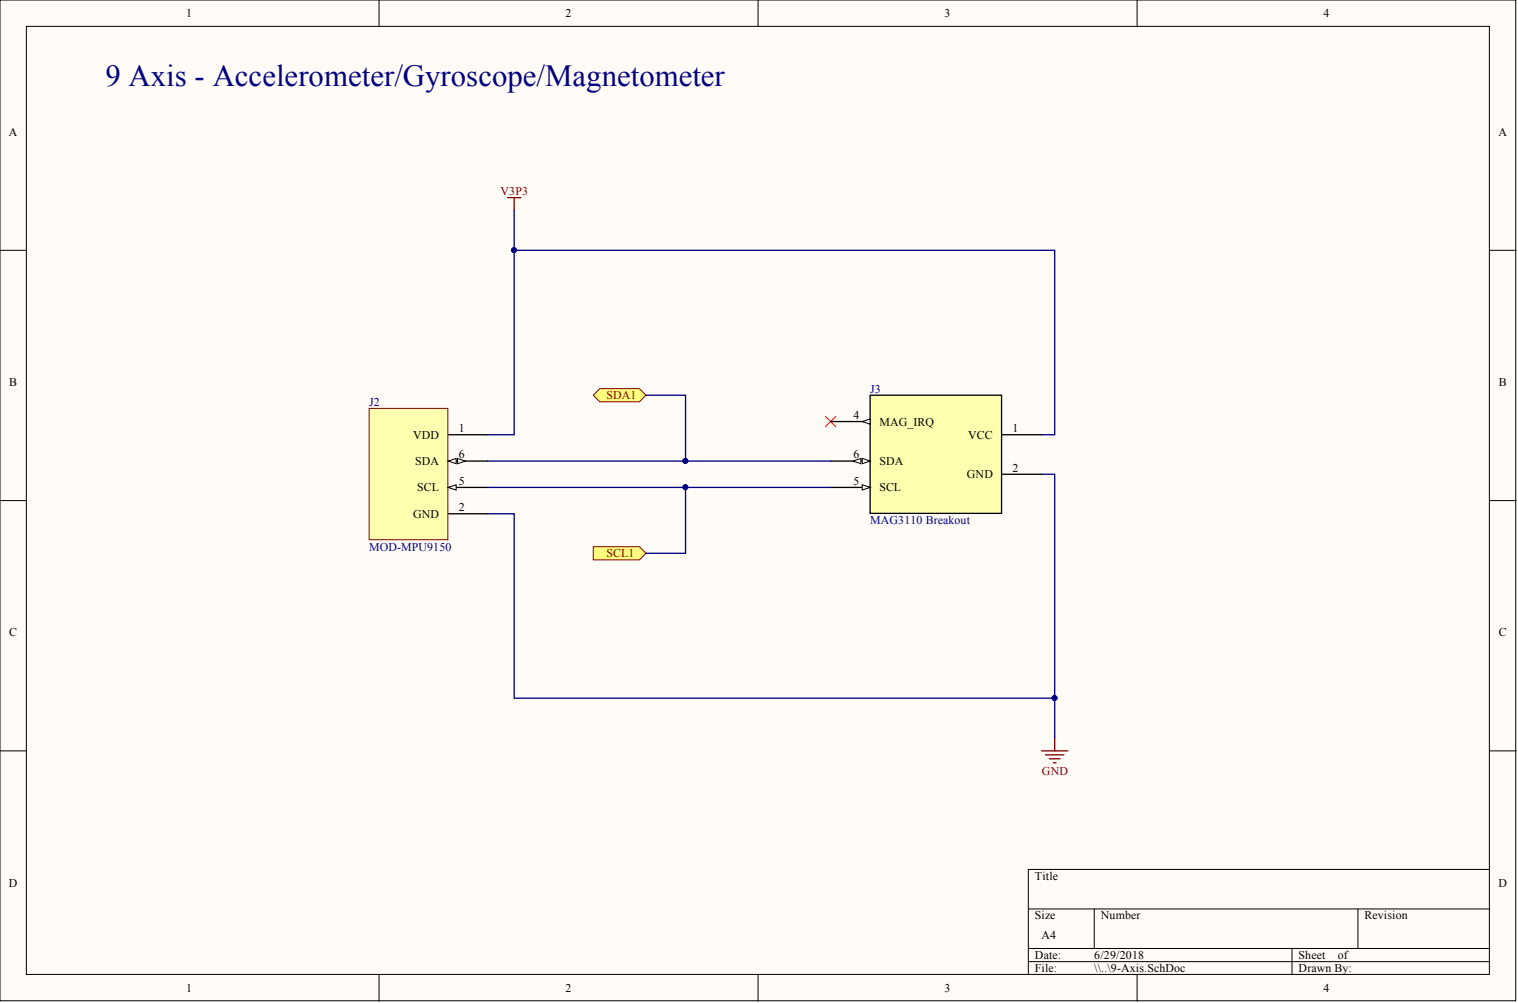
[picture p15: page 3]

9 Axis - Accelerometer/Gyroscope/Magnetometer



GND 6

GPIO7/RTS/SPI_CS 8



BT connection status toggle on discovery



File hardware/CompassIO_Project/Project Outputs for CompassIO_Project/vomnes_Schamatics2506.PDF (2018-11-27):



OSC1 | | OSC1/CLKI/RPA2/RA2 9

OSC2/CLKO/RPA3/PMA0/RA3 10 SOSCI/RPB4/RB4 11 SOSCO/RPA4/T1CK/CTED9/PMA1/RA4 12 VDD 13 | 10μF

SDA1


9 Axis - Accelerometer/Gyroscope/Magnetometer





BT connection status toggle on discovery



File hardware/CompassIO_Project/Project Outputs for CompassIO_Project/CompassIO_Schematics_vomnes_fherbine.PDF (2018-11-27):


9 Axis - Accelerometer/Gyroscope/Magnetometer





GND 6

GPIO7/RTS/SPI_CS 8


BT connection status toggle on discovery


VDD 2

VSS 3

PGED 4 PGEC 5 NC 6



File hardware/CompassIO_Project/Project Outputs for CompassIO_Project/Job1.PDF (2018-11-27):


9 Axis - Accelerometer/Gyroscope/Magnetometer





GND 6

GPIO7/RTS/SPI_CS 8


BT connection status toggle on discovery


VDD 2

VSS 3

PGED 4 PGEC 5 NC 6



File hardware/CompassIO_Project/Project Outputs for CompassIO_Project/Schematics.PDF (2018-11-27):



OSC1 | | OSC1/CLKI/RPA2/RA2 9

OSC2/CLKO/RPA3/PMA0/RA3 10 SOSCI/RPB4/RB4 11 SOSCO/RPA4/T1CK/CTED9/PMA1/RA4 12 VDD 13 | 10μF

SDA1


9 Axis - Accelerometer/Gyroscope/Magnetometer





BT connection status toggle on discovery



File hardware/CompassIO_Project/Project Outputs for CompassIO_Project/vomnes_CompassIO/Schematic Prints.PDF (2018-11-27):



OSC1 | | OSC1/CLKI/RPA2/RA2 9

OSC2/CLKO/RPA3/PMA0/RA3 10 SOSCI/RPB4/RB4 11 SOSCO/RPA4/T1CK/CTED9/PMA1/RA4 12 VDD 13 | 10μF

SDA1

VDD 2

VSS 3

PGED 4 PGEC 5 NC 6


9 Axis - Accelerometer/Gyroscope/Magnetometer



GND 6

GPIO7/RTS/SPI_CS 8



BT connection status toggle on discovery











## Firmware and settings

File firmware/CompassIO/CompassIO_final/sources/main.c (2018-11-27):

#include "types.h"

struct s_data data;
struct s_taskflag thisTaskFlag;

#define NEWLINE '#'

void HandleBluetooth(struct s_data *data_s);
char buffBT[500];
u8 dest_selected = 0;
#define FIFO_SIZE 256

char pbBuffer[FIFO_SIZE];
char *pbPut;
char *pbGet;

void FIFOInit(void)
{
    pbPut = pbBuffer;
    pbGet = pbBuffer;
}

void FIFOPut(char bInput)
{
    *pbPut = bInput;
    pbPut++;

    if (pbPut >= (pbBuffer + FIFO_SIZE))
        pbPut = pbBuffer;
}

char FIFOGet(void)
{
    char bReturn;

    bReturn = *pbGet;
    pbGet++;

    if (pbGet>= (pbBuffer + FIFO_SIZE))
        pbGet= pbBuffer;
	return(bReturn);
}

/* UART -> GPS */
void __ISR(_UART1_VECTOR, IPL1) UART1Handler(void) {
	// Reception
	if (IFS1bits.U1RXIF) {
		IFS1bits.U1RXIF = 0;
		HandleBluetooth(&data);
		thisTaskFlag.Bluetooth = TRUE;
	}
}

u8 tch = '0';
/* UART -> Bluetooth/Debug */
void __ISR(_UART2_VECTOR, IPL1) UART2Handler(void) {
	// Reception
	IFS1bits.U2RXIF = 0;
	char bReceived;

    // Receive Data Ready
    // there is a 4 byte hardware Rx fifo, so we must be sure to get all read bytes
   // while(U2STAbits.URXDA)
   // {
        bReceived = U2RXREG;

        // only usethe data if there was no error
        if ((U2STAbits.PERR == 0) && (U2STAbits.FERR == 0))
        {

             // Put your data into a queue
             FIFOPut(bReceived);
			 if (bReceived == 10)
			 {
				 __builtin_disable_interrupts();
				U2MODEbits.ON = 0;
				__builtin_enable_interrupts();
			 }

        }

  //  }      // clear rx interrupt flag
}

u16 countTime = 0;
u8  countTimeEnable = FALSE;
u8  devicePowered = FALSE;
unsigned char  rst = 0, on_off = 0, gps = 0;
unsigned short gpsTmp = 0;

u8 powerOnProcess = FALSE;
u8 powerOffProcess = FALSE;

void	gps_power_on(void)
{
	if (gpsTmp % 100 == 0)
		LATBbits.LATB2 ^= 1;													//// POWER ON LED
	if (gpsTmp == 100 && !rst) // 100ms after PIC power on
	{
		LATBbits.LATB3 = 1;
		rst = 1;
	}
	else if (gpsTmp == 110 && !on_off)
	{
		LATBbits.LATB5 = 1;
		on_off = 1;
	}
	else if (gpsTmp == 310 && on_off)
	{
		LATBbits.LATB5 = 0;
		on_off = 0;
	}
	else if (gpsTmp > 310)
	{
		gpsTmp = 0;
		gps = 1;
		powerOnProcess = FALSE;
		///////////////////////////////////////////////////////////////////////////////////// SHOULD ENABLE BT HERE
	}
}

void	gps_power_off(void)
{
	gps = 0;
	if (gpsTmp == 0)
		LATBbits.LATB5 = 1;
	else if (gpsTmp == 200)
	{
		LATBbits.LATB5 = 0;
		powerOffProcess = FALSE;
	}
	gpsTmp++;																	/// WARNING
}

#define MAX_U16 0xFFFF

/* Calibrate MAG3110 */
s16	x_min;
s16	x_max;
s16	y_min;
s16	y_max;

s16 offset_x = 0;
s16 offset_y = 0;

float x_scale = 0;
float y_scale = 0;

s32 TimerCalMode = 0;

u16 counter = 0;

void __ISR(_TIMER_3_VECTOR, IPL1) Timer3Handler(void) {
	IFS0bits.T3IF = 0;
    /* Power Off 2 Sec */
    if (countTimeEnable && countTime < MAX_U16)
        countTime++;
    /* ON OFF GPS Sequence */
    if (powerOnProcess)
        gps_power_on();
    if (powerOffProcess)
        gps_power_off();
	if (thisTaskFlag.CalMag)
		TimerCalMode++;
	counter = (counter < 0xFFFF) ? counter + 1 : 0;
    gpsTmp = (gpsTmp <= 500) ? gpsTmp + 1 : 500 ;			//overflow
}

void blink_distance(struct s_data *datas)
{
	if (counter % ((6 * datas->current_distance * 100) / datas->init_distance + 100))
		LATBbits.LATB2 ^= 1;
}

void storeMagData(s16 x_max, s16 x_min, s16 y_max, s16 y_min) {
	s16 x_tab[2] = {x_max, x_min};
	s16 y_tab[2] = {y_max, y_min};
	erase_sector(STORE_MAG_X);
	delayms(85);
	store_several_datas(STORE_MAG_X, x_tab, 2, 2);
	delayms(85);
	erase_sector(STORE_MAG_Y);
	delayms(85);
	store_several_datas(STORE_MAG_Y, y_tab, 2, 2);
	delayms(85);
}

void calibrateMag(s16 x, s16 y)
{
	if(x < x_min)
	  x_min = x;
	if(x > x_max)
	  x_max = x;
	if(y < y_min)
	  y_min = y;
	if(y > y_max)
	  y_max = y;
	if(TimerCalMode > 5000) // Exit calibration
	{
		thisTaskFlag.CalMag = FALSE;
		LATBbits.LATB2 = 0;
		offset_x = (x_min + x_max) / 2;
		offset_y = (y_min + y_max) / 2;
		x_scale = 1.0/(float)(x_max - x_min);
		y_scale = 1.0/(float)(y_max - y_min);
		/* Back Timer4 on 500ms frequency */
		PR4 = PBCLK/256/2;
		TMR4 = 0;
		/* ======================= */
		storeMagData(x_max, x_min, y_max, y_min);
	}
}

#define DEG_PER_RAD (180.0/3.14159265358979)

s16 readHeading(s16 x, s16 y)
{
	float xf = (float) x * 1.0f;
	float yf = (float) y * 1.0f;

	//Calculate the heading
	return (atan2(-yf*y_scale, xf*x_scale) * DEG_PER_RAD);
}

void Mag(s16 x, s16 y, struct s_data *datas) {
	if (devicePowered) {
		s16 degrees = (int)readHeading(x - offset_x, y - offset_y);
		s16 azimut = 0;
		if (datas->dest_coord.completed == TRUE && datas->current_coord.completed == TRUE)
		{
            ft_putendl("here");
			azimut = get_direction(datas->current_coord.lat, datas->current_coord.lon, datas->dest_coord.lat, datas->dest_coord.lon);
			azimut = (azimut > 180) ? -1 * (360 - azimut) : azimut;
			if (degrees + azimut >= -180 && degrees + azimut <= 180)
				degrees = (degrees + azimut) / 2;
			else if (degrees + azimut < -180)
				degrees = (360 + (degrees + azimut))/2;
			else if (degrees + azimut > -180)
				degrees = (360 - (degrees + azimut))/2;
			if (degrees < -90 || degrees > 90)
				degrees = (degrees > 90) ? 0 : 180;
			else
				degrees = 90 - degrees;
			if (thisTaskFlag.displayDist == TRUE)
				ServoMotorSetAngle(degrees);
		}
		thisTaskFlag.Mag = 0;
	}
}


void __ISR(_TIMER_4_VECTOR, IPL6) Timer4Handler(void) {
    IFS0bits.T4IF = 0;
	thisTaskFlag.Mag = 1;
}

void Init_Timer4()
{
  T4CON = 0;               // 0 on every bit, (timer stop, basic config)
  TMR4 = 2;                // Clean the timer register

  IPC4bits.T4IP = 6; // Set priority
  IPC4bits.T4IS = 1; // Set subpriority
  IFS0bits.T4IF = 0;       // Clear interrupt status flag
  IEC0bits.T4IE = 1; // Enable interrupts

  T4CONbits.TCKPS = 0b111; // Set scaler 1:256
  PR4 = PBCLK/256/2;    // Setup the period
  T4CONbits.ON = 1;
}

void mag_offset_init(void)
{
	read_id();
	/* MAG - OFFSET */
	x_max = (s16)read_index_data(STORE_MAG_X, 2, 0);
    delayms(85);
	x_min = (s16)read_index_data(STORE_MAG_X, 2, 1);
    delayms(85);
	y_max = (s16)read_index_data(STORE_MAG_Y, 2, 0);
    delayms(85);
	y_min = (s16)read_index_data(STORE_MAG_Y, 2, 1);
	delayms(85);
	/* ft_putstr("mag x ");
	ft_putbinary(x_max);
	ft_putstr(" - ");
	ft_putbinary(x_min);
	ft_putendl("");
	ft_putstr("mag y ");
	ft_putbinary(y_max);
	ft_putstr(" - ");
	ft_putbinary(y_min);
	ft_putendl("");*/
}

void global_init()
{
    __builtin_disable_interrupts();
    UART1_Init(_8N, 0, UART_RX_TX_ON);
    UART2_Init(_8N, 0, UART_RX_TX_ON);
    init_servo();
    Init_SPI1();
    I2C1_Init();
    Init_Timer4();
    INTCONbits.MVEC = 1; // Enable multi interrupts
    __builtin_enable_interrupts();
    init_mag();
    /* GPS */
    LATBbits.LATB5 = 0;
    LATBbits.LATB3 = 0;
	FIFOInit();
    rst = 0;
    on_off = 0;
    gps = 0;
	ft_bzero(buffBT, 500);
    mag_offset_init();
	init_struct_datas(&data);
	dest_selected = 0;
	/*	data->dest_coord.lat = (float)(((u32)read_data(STORE_DEST_LAT_X1000, 4)) / 1000);
		delayms(85);
		data->dest_coord.lon = (float)(((u32)read_data(STORE_DEST_LONG_X1000, 4)) / 1000);
		if (data->dest_coord.lat != 0.0 && data->dest_coord.lon != 0.0) {
			data->dest_coord.completed = TRUE;
		}*/                                                                 // >>>>>>>> COMMENT
    offset_x = (x_min + x_max) / 2;
    offset_y = (y_min + y_max) / 2;
    x_scale = 1.0/(float)(x_max - x_min);
    y_scale = 1.0/(float)(y_max - y_min);
    delayms(50);
}

void global_off()
{
    U1MODEbits.ON = 0; // Disable UART1 Module
    U2MODEbits.ON = 0; // Disable UART2 Module
    I2C1CONbits.ON = 0; // Disable I2C1
    SPI2CONbits.ON = 0; // Disable SPI2 Flash Memory
    T2CONbits.ON = 0;  // Disable Timer2 Servomotor
}

void store_datas(void)
{
	erase_sector(STORE_DEST_LAT_X1000);
	delayms(200);
	write_data(STORE_DEST_LAT_X1000, ((int)(data.dest_coord.lat * 1000)), 4);
	delayms(85);
	erase_sector(STORE_DEST_LONG_X1000);
	delayms(200);
	write_data(STORE_DEST_LONG_X1000, ((int)(data.dest_coord.lon * 1000)), 4);
	delayms(85);
}

#define ONE_HALF_SEC 1500
#define FIVE_SEC 5000


void __ISR(_EXTERNAL_1_VECTOR, IPL1) MainButtonHandler(void) {
	if (INTCONbits.INT1EP == 0) { // Button Released
		if (devicePowered && countTime > FIVE_SEC)
		{
			ft_putendl("Enter in calibration mode");
			/* Set Timer4 on 100ms frequency */
			PR4 = PBCLK/256/10;
			TMR4 = 0;
			/* ============================== */
			// Clear offset
			offset_x = 0;
			offset_y = 0;
			x_min = 0x7FFF;														//// ?
			x_max = 0x8000;														//// ?
			y_min = 0x7FFF;														//// ?
			y_max = 0x8000;														//// ?
			thisTaskFlag.CalMag = TRUE;
			LATBbits.LATB2 = 1;
			TimerCalMode = 0;
		}
		else if (devicePowered && countTime > ONE_HALF_SEC)
		{
			powerOnProcess = FALSE;
			powerOffProcess = TRUE;
			gpsTmp = 0;
			ft_putendl("GLOBAL POWER OFF");
			//global_off();										>>>>>>>>>>>>>>> CRASH !!!
			devicePowered = FALSE;
			dest_selected = 0;
			LATBbits.LATB2 = 0;
		}
		else if(countTime > 10)
		{
			if (devicePowered  && data.store_data && !dest_selected)
			{
				ft_putendl("start");
				store_datas();
				ft_putendl("okok");
				data.store_data = FALSE;
				dest_selected = 1;
				//U1MODEbits.ON = 0;											// AFTER
				//U2MODEbits.ON = 1;
//				__builtin_disable_interrupts();
//				U2MODEbits.ON = 1;
//				__builtin_enable_interrupts();
//				ft_bzero(buffGPS, 500);
				LATBbits.LATB2 = 1;
			}
			else if (devicePowered && !dest_selected)
			{
				ft_putendl("start");
				dest_selected = 1;
				//U1MODEbits.ON = 0;
//				__builtin_disable_interrupts();
//				U2MODEbits.ON = 1;
//				__builtin_enable_interrupts();
//				ft_bzero(buffGPS, 500);
				LATBbits.LATB2 = 1;
			}
			else if (devicePowered && dest_selected)
			{
			    ft_putendl("destination switch");
				thisTaskFlag.switchPos = TRUE;
			}
			else
			{
			    powerOnProcess = TRUE;
				powerOffProcess = FALSE;
			    gpsTmp = 0;
			    global_init();
			    ft_putendl("first time = GLOBAL POWER ON");
			    devicePowered = TRUE;
			}
		}
			countTime = 0;
			countTimeEnable = FALSE;
			INTCONbits.INT1EP = 1;
			// Get button pushing instead of getting release
		} else { // Button pressed
			countTimeEnable = TRUE;
			INTCONbits.INT1EP = 0; // Active button1 release mode
		}
		IFS0bits.INT1IF = 0; // Reset to 0 Interrupt INT1
}

void init_button()
{
	INTCONbits.INT1EP = 1; //1->lorsqu'on entre, 0 lorsqu'on sort l'interrupt se produit*/

	// INT1 - Button
	IPC1bits.INT1IP = 1;
	IPC1bits.INT1IS = 0;
	IFS0bits.INT1IF = 0;
	IEC0bits.INT1IE = 1;
}

void HandleBluetooth(struct s_data *data_s) {
	// Store input in buffer
	u32 dest_len = ft_strlen(buffBT);
	u8 res = 0;
	buffBT[dest_len] = UART1_Get_Data_Byte();
	UART1_Send_Data_Byte(buffBT[dest_len]);
	buffBT[dest_len + 1] = '\0';
	if (buffBT[dest_len] == NEWLINE) {
		buffBT[dest_len] = '\0';
		//ft_putendl(buffBT);
		//ft_putnbr_base(IFS1bits.U2RXIF, 10);
		res = parser_gps_bluetooth(buffBT, data_s);
		//ft_putnbr_base(data_s->store_data, 10);
		//ft_putendl("<< toto");
		//ft_putnbr_base(dest_selected, 10);
		//ft_putendl("<< toto");
		ft_bzero(buffBT, 500);
	}
}

//void parse_GPS(struct s_data *data_s)
//{
//	u32 dest_len = 0;
//	u8 res = -1;
//	buffGPS[0] = '$';
//	buffGPS[1] = '\0';
//	while(UART2_Get_Data_Byte() != '$');
//	while (res != 1)
//	{
//	while(buffGPS[dest_len] != 10)
//	{
//		dest_len = ft_strlen(buffGPS);
//		buffGPS[dest_len] = UART2_Get_Data_Byte();
//
//		if (dest_len > 0 && buffGPS[dest_len - 1] == 13 && buffGPS[dest_len] == 10)
//		{
//			if (!ft_strncmp(buffGPS, "$GPRMC,", 7)) {
//				buffGPS[dest_len - 1] = '\0';
//				buffGPS[dest_len] = '\0';
//				ft_putendl(buffGPS);
//				res = parse_nmea_gps(buffGPS, data_s);
//				if (res == 1)
//				{
//					ft_putfloat(data_s->current_coord.lat);
//					UART1_Send_Data_Byte('-');
//					ft_putfloat(data_s->current_coord.lon);
//				}
//			}
//			ft_bzero(buffGPS, 500);
//		}
//	}
//	}
//}

//
//void HandleGPS(struct s_data *data_s, char *buff) {
//	u32 dest_len = ft_strlen(buffGPS);
//	u8 res = -1;
//
//	//buffGPS[dest_len] = UART2_Get_Data_Byte();
//	__builtin_disable_interrupts();
//	U2MODEbits.ON = 0;
//	__builtin_enable_interrupts();
//
////	if (dest_len == 0)
////		UART2_Send_Data_Byte('|');
////	else if (buffGPS[dest_len] == 10)
////		UART2_Send_Data_Byte('|');
//	//UART2_Send_String(buffGPS, ft_strlen(buffGPS));
//	buffGPS[dest_len + 1] = '\0';
//
//	if (dest_len > 0 && buffGPS[dest_len - 1] == 13 && buffGPS[dest_len] == 10)
//	{
//		//UART2_Send_String("toto\n", ft_strlen("toto\n"));
//		if (!ft_strncmp(buffGPS, "$GPRMC,", 7)) {
//			buffGPS[dest_len - 1] = '\0';
//			buffGPS[dest_len] = '\0';
//			res = parse_nmea_gps(buffGPS, data_s);
//			if (res == 1)
//			{
//				ft_putfloat(data_s->current_coord.lat);
//				//UART2_Send_Data_Byte('-');
//				ft_putfloat(data_s->current_coord.lon);
//			}
//		}
//		//dest_len = 0;
//		//UART2_Send_Data_Byte('|');
//		//UART2_Send_String(buffGPS, dest_len);
//		//UART2_Send_Data_Byte('|');
//		ft_bzero(buffGPS, 500);
//	}
//	//LATBbits.LATB1 ^= 1;
//	__builtin_disable_interrupts();
//	U2MODEbits.ON = 1;
//	__builtin_enable_interrupts();
//}

void init_task_flags(void)
{
	thisTaskFlag.Bluetooth = FALSE;
	thisTaskFlag.CalMag = FALSE;
	thisTaskFlag.GPS = FALSE;
	thisTaskFlag.Mag = FALSE;
	thisTaskFlag.switchPos = FALSE;
	thisTaskFlag.displayDist = FALSE;
}

void flags_status(void)
{
	ft_putstr("thisTaskFlag.Bluetooth : ");
	ft_putendl(thisTaskFlag.Bluetooth ? "TRUE" : "FLASE");

	ft_putstr("thisTaskFlag.Mag : ");
	ft_putendl(thisTaskFlag.Mag ? "TRUE" : "FLASE");

	ft_putstr("thisTaskFlag.GPS : ");
	ft_putendl(thisTaskFlag.GPS ? "TRUE" : "FLASE");
	ft_putendl("");
}

void reg_stat(void)
{
	ft_putstr("IFS1bits.U2RXIF : ");
	ft_putendl(IFS1bits.U2RXIF ? "1" : "0");
	ft_putstr("IEC1bits.U2RXIE : ");
	ft_putendl(IEC1bits.U2RXIE ? "1" : "0");
}

u16 i = 0;
char line[FIFO_SIZE];
u8 tstchr;
int x = 0;

void main()
{
	//struct s_data *data;
	SET_USER_LED(OUTPUT); // LED writable
	USER_LED_ON(FALSE);
	TRISBbits.TRISB5 = 0; // RD6 is an output -> ON_OFF GPS
	LATBbits.LATB5 = 0;
	TRISBbits.TRISB3 = 0; // RD5 is an output -> nRST GPS
    LATBbits.LATB3 = 1;

	set_pps();
	init_task_flags();
	s16 mag_x = 0.0, mag_y = 0.0, mag_z = 0.0;

	__builtin_disable_interrupts();
	Init_Delay();
	init_button();
	init_servo();
	ServoMotorSetAngle(180);
	INTCONbits.MVEC = 1; // Enable multi interrupts
	__builtin_enable_interrupts();
        //ft_putendl("start");
	// Set each element of the struc to NULL
	//ft_memset(&thisTaskFlag, 0, sizeof(thisTaskFlag)); // USELESS ?
	//ft_memset(&data, 0, sizeof(data));                 // USELESS ?
	while (1) {
		//ft_putendl("loop");
		//reg_stat();
		if (thisTaskFlag.displayDist == FALSE && data.current_coord.completed == TRUE)
			thisTaskFlag.displayDist = TRUE;
		if (thisTaskFlag.Mag == 1) {
			//ft_putendl("");
			//ft_putendl("===>> mag <<===");
			readMag(&mag_x, &mag_y, &mag_z);
			Mag(mag_x, mag_y, &data);													/// ?
			if (thisTaskFlag.CalMag == 1) {
				calibrateMag(mag_x, mag_y);
			}
		}
		if (thisTaskFlag.Bluetooth == 1) {
			thisTaskFlag.Bluetooth = 0;
		}
		if (thisTaskFlag.GPS == 1 || dest_selected) {
			while(i < 128)
			{
				FIFOPut(UART2_Get_Data_Byte());
				//}
				//UART1_Send_Data_Byte(line[i]);
				//if (line[i] == 10)
				//	break ;
				i++;
				
			}
			i = 0;
			while(i < 128 && FIFOGet() != '$');
			while(i < 128)
			{
				line[x] = FIFOGet();
				//UART1_Send_Data_Byte(line[x]);
				if (x > 0 && line[x] == 10 && line[x - 1] == 13)
				{
					line[i - 1] = 0;
					line[i] = 0;
					if (!ft_strncmp(line, "$GPRMC,", 7))
					{
						u8 res = 0;
						ft_putendl("parse");
						res = parse_nmea_gps(line, &data);
						if (res == 1)
						{
							ft_putendl(">>>>>>>>>>>>>>>>>>>> parsed");
							ft_putfloat(data.current_coord.lat);
							UART1_Send_Data_Byte('-');
							ft_putfloat(data.current_coord.lon);
						}
					}
					else
					{
						//ft_putendl("no parsing");
					}
					x = 256;													//////
				}
				i++;
				x = (x == 256) ? 0 : x + 1;
			}

			i = 0;
			FIFOInit();
//			line[i] = 0;
//			line[i - 1] = 0;
//			//delayms(10);
//			for (x = 0; x < 64; x++)
//				UART1_Send_Data_Byte(line[x]);
//			ft_putendl("titi");
//			for (x = 0; x < 199; x++)
//				line[i] = 0;
//			i = 0;
//			ft_putendl("toto");
//			thisTaskFlag.GPS = 0;
		}
		if (thisTaskFlag.switchPos == TRUE)
		{
			switch_position(&data);
			thisTaskFlag.switchPos = FALSE;
		}
		if (thisTaskFlag.displayDist == TRUE)
			blink_distance(&data);

		if (thisTaskFlag.displayDist == TRUE && data.current_distance <= 10){		// the walk is over 10m near from the final destination
			thisTaskFlag.displayDist = FALSE;
			LATBbits.LATB2 = 1;
		}
	}
}

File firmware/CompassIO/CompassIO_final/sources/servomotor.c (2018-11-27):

#include "types.h"

void ServoMotorSetAngle(u8 dutyCycle)
{
	if (dutyCycle > 180)
		dutyCycle = 180;
	OC1RS = (PR2 + 1) * ((float)dutyCycle/1890 + 0.035); //0.035 -> 1ms Offset
}

void init_servo()
{
	TRISBbits.TRISB7 = 0;
	LATBbits.LATB7 = 0;

	T2CON = 0;               // 0 on every bit, (timer stop, basic config)
	TMR2 = 0;                // Clean the timer register
	IFS0bits.T2IF = 0;     // Clear interrupt status flag
	T2CONbits.TCKPS = 0b101; // Set scaler 1:16
	PR2 = PBCLK/32/50;    // Setup the period > Periph. Bus Clk (set by user) / scaler > sec | 20ms

	T2CONbits.ON = 1;

	OC1CONbits.OCM = 0b110;
	ServoMotorSetAngle(0);
	OC1CONbits.ON = 1;
}

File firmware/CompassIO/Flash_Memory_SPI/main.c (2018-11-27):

/* 
 * File:   main.c
 * Author: bocal
 *
 * Created on May 24, 2018, 10:18 AM
 */

#include <p32xxxx.h>

#define _CS1_ON() (PORTDbits.RD5 = 0)
#define _CS1_OFF() (PORTDbits.RD5 = 1)

// DEVCFG2
#pragma config FPLLIDIV = DIV_2         // PLL Input Divider (2x Divider)
#pragma config FPLLMUL = MUL_20         // PLL Multiplier (20x Multiplier)
#pragma config FPLLODIV = DIV_1         // System PLL Output Clock Divider (PLL Divide by 1)

// DEVCFG1
#pragma config FNOSC = PRIPLL           // Oscillator Selection Bits (Primary Osc w/PLL (XT+,HS+,EC+PLL))
#pragma config POSCMOD = HS             // Primary Oscillator Configuration (HS osc mode)

#define SYSCLK (8000000/2*20/1) // = 80Mhz
#define PBCLK (SYSCLK/8) // = 10 Mhz //
//#define Fsck 5000

#define SPI_BAUD_RATE 1
typedef unsigned char u8;
typedef unsigned short u16;
typedef unsigned long u32;
typedef long s32;

#define MAX_BUFFER_SIZE 256

#define UART_BAUD_RATE ((PBCLK/9600/16)-1)


void Init_Delay()
{
  T3CON = 0;               // 0 on every bit, (timer stop, basic config)
  TMR3 = 2;                // Clean the timer register
  IFS0bits.T3IF = 0;       // Clear interrupt status flag
  T3CONbits.TCKPS = 0b111; // Set scaler 1:256
  PR3 = PBCLK/256/1000;    // Setup the period
  T3CONbits.ON = 1;
}

void delayms(u32 ms) {
    while (ms)
	if (IFS0bits.T3IF == 1) {
	    IFS0bits.T3IF = 0;
	    ms--;
	}
}
/*
 * 
 */

/* UART2 */

void UART2_Init(u8 parityDataBits, u8 stopBits, u8 TRX_Mode)
{
    if (!TRX_Mode) {
	return;
    }
    U2BRG = UART_BAUD_RATE;
    U2MODEbits.PDSEL = parityDataBits;
    U2MODEbits.STSEL = stopBits;
    U2STAbits.URXEN = TRX_Mode != 1; // Enable reception
    U2MODEbits.ON = 1; // Enable UART1 Module
    U2STAbits.UTXEN = TRX_Mode & 1; // Enable transmission and set UxTXIF (Int)
}

void UART2_Send_Data_Byte(u8 data)
{
    while (U2STAbits.UTXBF);
    U2TXREG = data;
}

u8 UART2_Send_String(const char *string, u32 size)
{
    if ((string == NULL) || (size > MAX_BUFFER_SIZE))
	return (-1);
    u32 i;
    for (i = 0; i < size; i++)
	UART2_Send_Data_Byte(string[i]);
    return (0);
}

u32		ft_strlen(const char *s)
{
	char *str = s;
	while (*s++);
	return (s-str);
}

void ft_putstr(char *string)
{
   UART2_Send_String(string, ft_strlen(string));
}

void *ft_bzero(void *s, u32 size)
{
    char *str;

    str = (char*)s;
    while (size--)
    {
	*str = 0;
	str++;
    }
    return (s);
}
static s32	ft_count(s32 nb, char base)
{
	int count;

	count = 0;
	if (nb == 0)
		return (1);
	while (nb > 0)
	{
		nb = nb / base;
		count++;
	}
	return (count);
}

void	        ft_putnbr_base(s32 nb, int base)
{
	s32	n;
	int	sign_len[2];
	char	str[32];

	n = nb;
	sign_len[1] = 0;
	if (n < 0)
		n = -n;
	if (n < 0 && base == 10)
		sign_len[1] = 1;
	ft_bzero(str, 32);
	sign_len[0] = ft_count(n, base) + sign_len[1];
	sign_len[0]--;
	if (nb == 0)
		str[sign_len[0]] = '0';
	while (n)
	{
		(n % base <= 9) ? (str[sign_len[0]--] = (n % base) + '0') :
		(str[sign_len[0]--] = (n % base) + 'A' - 10);
		n /= base;
	}
	if (sign_len[1] == 1)
		str[sign_len[0]] = '-';
	ft_putstr(str);
	ft_putstr("\n\r");
}
void ft_putbinary(u32 nb)
{
    char str[35];
    u8 i;
    ft_bzero(str, 35);
    str[0] = '0';
    str[1] = 'b';
    for (i = 0; i < 32; i++) {
	str[33-i] = '0' + ((nb >> i) & 1);
    }
    ft_putstr(str);
	ft_putstr("\n\r");
}
/* ===== */


void SPI2_Write(unsigned char data)
{
    while (!SPI2STATbits.SPITBE); // SPI Transmit Buffer Full Status bit
    SPI2BUF = data;
}

void Handle_SPI(unsigned char input, unsigned char *output)
{
    SPI2BUF = input;
    while (!SPI2STATbits.SPIRBF);
    *output = SPI2BUF;
}

unsigned char SPI2_Read()
{
    if (SPI2STATbits.SPIRBF)     // Receive buffer is full - Auto cleared
    {
      if (SPI2STATbits.SPIROV)
      {
        SPI2STATbits.SPIROV = 0; // Overflow has occured
        return (0xff);
      }
      return (SPI2BUF & 0xFF);   // 8-bit mode
    }
    return (0);
}

#define FM_JEDECID 0x9F
#define FM_ID 0xAB
#define FM_WRITE_ENABLE 0x06
#define FM_WRITE_DISABLE 0x04
#define FM_PAGE_PROGRAM 0x02
#define FM_READ 0x03
#define FM_STATUS_REGISTER_READ 0x05
#define FM_ERASE_SECTOR 0xD8

void send_addr(u32 addr)
{
    u8 output;

    Handle_SPI((addr >> 16) & 0xFF, &output);
    Handle_SPI((addr >> 8) & 0xFF, &output);
    Handle_SPI(addr & 0xFF, &output);
}

void erase_sector(u32 addr)
{
    u8 output;

    _CS1_ON();
    Handle_SPI(FM_WRITE_ENABLE, &output);
    _CS1_OFF();
    delayms(100);
    _CS1_ON();
    Handle_SPI(FM_ERASE_SECTOR, &output);
    send_addr(addr);
    _CS1_OFF();
}

void write_data(u32 addr, u8 *data, u32 size)
{
    u32 i = 0;
    u8 output;

    erase_sector(addr);
    delayms(200);
    _CS1_ON();
    Handle_SPI(FM_WRITE_ENABLE, &output);
    _CS1_OFF();
    delayms(100);
    _CS1_ON();
    Handle_SPI(FM_PAGE_PROGRAM, &output);
    send_addr(addr);
    while (i < size)
    {
	Handle_SPI(data[i], &output);
        i++;
    }
    _CS1_OFF();
}

void read_data(u32 addr, u32 size)
{
    u32 i = 0;
    u8 output;

    _CS1_ON();
    Handle_SPI(FM_READ, &output);
    send_addr(addr);
    while(i < size)
    {
        Handle_SPI(0x00, &output);
        if (output <= 127)
            UART2_Send_Data_Byte(output);
        i++;
    }
    _CS1_OFF();
}

void read_jedecid()
{
    _CS1_ON();
    u8 output;
    Handle_SPI(FM_JEDECID, &output);
    Handle_SPI(0, &output);
    ft_putnbr_base(output, 16);
    Handle_SPI(0, &output);
    ft_putnbr_base(output, 16);
    Handle_SPI(0, &output);
    ft_putnbr_base(output, 16);
    Handle_SPI(0, &output);
    ft_putnbr_base(output, 16);
    _CS1_OFF();
}

void read_id()
{
    _CS1_ON();
    u8 output;
    Handle_SPI(FM_ID, &output);
    Handle_SPI(0, &output);
    Handle_SPI(0, &output);
    Handle_SPI(0, &output);
    Handle_SPI(0, &output);
    ft_putnbr_base(output, 16);
    _CS1_OFF();
}

void read_status_register()
{
    _CS1_ON();
    u8 output;
    Handle_SPI(FM_WRITE_ENABLE, &output);
    _CS1_OFF();
    delayms(100);
    _CS1_ON();
    Handle_SPI(FM_STATUS_REGISTER_READ, &output);
   // Handle_SPI(0x0, &output);
    ft_putnbr_base(output, 16);
    Handle_SPI(FM_WRITE_DISABLE, &output);
    _CS1_OFF();
    delayms(100);
    _CS1_ON();
    Handle_SPI(FM_STATUS_REGISTER_READ, &output);
    Handle_SPI(0x0, &output);
    ft_putnbr_base(output, 16);
    _CS1_OFF();
}

void Init_SPI2()
{
    SPI2BRG = 127; // Set baud rate
    SPI2CONbits.MSTEN = 1; // MSTEN is to enable master mode
    SPI2CONbits.CKE = 1;
    SPI2CONbits.CKP = 0;
    SPI2CONbits.ON = 1;
    TRISDbits.TRISD5 = 0; // writeable
}
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

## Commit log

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2018-02-15 adding courses - tp2
    [PcbLib-TP2-Foot.PcbLib]
2018-02-15 Adding courses - tp1
    [PIC.SchDoc, PcbLib-TP2.PcbLib, Power.SchDoc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]
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2018-11-27 feat: Add total project
    [Bill of Materials.xls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]
2018-11-27 feat: Add additional docs
    [PCB_Project_Board.PcbDoc]
2018-11-27 feat: Add docs
    [Board_TP3.PcbDoc, PcbLib_1.PcbLib]
2018-11-27 feat: Add schema lib + update board
    [Bill of Materials.xls]
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2018-11-27 feat: Update schema footprint holes
    [Bill of Materials.xls, Board_TP3.PcbDoc, PIC.SchDoc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]
2018-11-27 feat: Shematics OK -> Ready for routing
    [Board_TP3.PcbDoc, LibSch.SchLib, PIC.SchDoc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]
2018-11-27 feat: Add routing
    [Board_TP3.PcbDoc, LibSch.SchLib, PIC.SchDoc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]
2018-11-27 feat: Finish Altium TP
    [Board_TP3.PcbDoc, PCB_Project_TP.PrjPcb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]
2018-11-27 feat: r
    [Board_TP3.PcbDoc, PCB_Project_TP.PrjPcb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]
2018-11-27 feat: Add mechanical drawing ++ Altium
    [Board_TP3.PcbDoc, PCB_Project_TP.PrjPcb]
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2018-11-27 feat: Start schematics compassIO
    [Bluetooth.SchDoc, CompassIO_Project.PrjPcb, Magnetometer.SchDoc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]
2018-11-27 feat: Add schematics
    [Bluetooth.SchDoc, CompassIO_Project.PrjPcb, Flash.SchDoc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]
2018-11-27 feat: All schematics ok - need check
    [Bluetooth.SchDoc, CompassIO_Project.PrjPcb, Flash.SchDoc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]
2018-11-27 feat: Update schematics, components properties and bill of materials
    [Bill of Materials-CompassIO_Project.xlsx, Bill of Materials.xls, Bluetooth.SchDoc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]
2018-11-27 feat: Add schematics cio
    [Bluetooth.SchDoc, CompassIO_Project.PrjPcb, Flash.SchDoc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]
2018-11-27 feat: Update schematics, add mosfet, led ref
    [Bill of Materials-CompassIO_Project.xlsx, Bluetooth.SchDoc, Flash.SchDoc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]
2018-11-27 feat: Finish schematics bom
    [Bill of Materials-CompassIO_Project.xlsx, Bill of Materials-CompassIO_Project_Soft.xlsx, Magnetometer.SchDoc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]
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2018-11-27 feat: MPU9150 - I2C Write doesn't work
    [main.c]
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2018-11-27 feat: Starting pcb lib
    [CompassIO_Project.PrjPcb, PcbLib1.PcbLib, Schlib.SchLib]
2018-11-27 feat: Add footprints components
    [PcbLib1.PcbLib]
2018-11-27 feat: Update footprints
    [PcbLib1.PcbLib]
2018-11-27 feat: Add schematics ICPS + Servomotor
    [CompassIO_Project.PrjPcb, Main.SchDoc, PcbLib1.PcbLib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]
2018-11-27 feat: Update schematics pic + compoenents
    [Bluetooth.SchDoc, Flash.SchDoc, GPS.SchDoc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]
2018-11-27 Updating schemes & pcb lib
    [CompassIO_Project.PrjPcb, PcbLib1.PcbLib, Schlib.SchLib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]
2018-11-27 feat: Update schamatics + compile it
    [9-Axis.SchDoc, Bluetooth.SchDoc, CompassIO.SchDoc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]
2018-11-27 Feat: Add power scheme
    [Bluetooth.SchDoc, CompassIO_Project.PrjPcb, Microcontroller.SchDoc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]
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2018-11-27 Feat: Add foot print inductor + cap e
    [CompassIO_Project.PrjPcb, PcbLib1.PcbLib, Power.SchDoc]
2018-11-27 feat: Correct schmatics errors + add MAG3110
    [9-Axis.SchDoc, Bluetooth.SchDoc, CompassIO.SchDoc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]
2018-11-27 feat: Add footprints c-grid
    [PcbLib1.PcbLib, ServoMotor.SchDoc]
2018-11-27 fix: Update PPS UART2
    [Led_rgb.SchDoc, Microcontroller.SchDoc]
2018-11-27 fix: Update footprints diameters holes (inductors) + footprints e cap
    [PcbLib1.PcbLib]
2018-11-27 fix: Correct errors after Gregoire review
    [Bluetooth.SchDoc, CompassIO.SchDoc, Flash.SchDoc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]
2018-11-27 feat: Footprints ready to import, need to add boutons
    [Bluetooth.SchDoc, Flash.SchDoc, GPS.SchDoc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]
2018-11-27 fix: Correct most of the schematic compilation errors
    [CompassIO.SchDoc, Led_rgb.SchDoc, Microcontroller.SchDoc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]
2018-11-27 fix: No more schematic compilation errors
    [Microcontroller.SchDoc]
2018-11-27 fix: Update global schematic page + MOSI/MISO
    [CompassIO.SchDoc, Flash.SchDoc, Led_rgb.SchDoc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]
2018-11-27 feat: Add schematics page numbers
    [9-Axis.SchDoc, Bluetooth.SchDoc, CompassIO.SchDoc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]
2018-11-27 feat: Start PCB, need to update some footprints
    [9-Axis.SchDoc, PCB1.PcbDoc, PcbLib1.PcbLib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]
2018-11-27 feat: Add routing, needs to add GND routing
    [Led_rgb.SchDoc, Microcontroller.SchDoc, PCB1.PcbDoc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]
2018-11-27 feat: Add GND routing
    [PCB1.PcbDoc]
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2018-11-27 feat: Update footprints mosfet 2N7002 + 0603 + schamtics
    [PcbLib1.PcbLib, Schlib.SchLib, ServoMotor.SchDoc]
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2018-11-27 feat: Update power schematics with new components
    [Microcontroller.SchDoc, Power.SchDoc, Schlib.SchLib]
2018-11-27 feat: Add new footprints power page
    [Microcontroller.SchDoc, PcbLib1.PcbLib, Power.SchDoc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]
2018-11-27 feat: Design 8 pins MOSFET
    [CompassIO_Project.PrjPcb, PCB2.PcbDoc, PcbLib1.PcbLib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]
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2018-11-27 feat: Add pcb power part
    [PCB2.PcbDoc, PcbLib1.PcbLib, Power.SchDoc]
2018-11-27 feat: Add all components on pcb
    [PCB2.PcbDoc]
2018-11-27 feat: Start routing (9-axis page gnd/vdd)
    [9-Axis.SchDoc, PCB2.PcbDoc]
2018-11-27 feat: Add routing wip
    [9-Axis.SchDoc, PCB2.PcbDoc]
2018-11-27 feat: Routing done ! NO routing errors
    [CompassIO_Project.PrjPcb, PCB2.PcbDoc, PcbLib1.PcbLib]
2018-11-27 feat: Polygone pour done
    [PCB2.PcbDoc]
2018-11-27 feat: Add serigraphy + start macanichal drawing
    [PCB2.PcbDoc, Power.SchDoc]
2018-11-27 feat: Add mecanichal drawing
    [PCB2.PcbDoc]
2018-11-27 feat: Add mecanichal drawing + holes corners + pour
    [PCB2.PcbDoc]
2018-11-27 feat: Add shield quartz + New generated documents (macanichal/drill)
    [CompassIO_Project.PrjPcb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]
2018-11-27 feat: All output files generated and sent to Gregoire
    [Bill of Materials-CompassIO_Project.xlsx, CompassIO_Project.PrjPcb, Led_rgb.SchDoc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]
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2018-11-27 feat: PCB updated (Power area - improve wires)
    [CompassIO_Project.PrjPcb, PCB2.PcbDoc, PcbLib1.PcbLib]
2018-11-27 feat: Add output files for Gregoire
    [PCB2.GBL, PCB2.GBO, PCB2.GBP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]
2018-11-27 feat: Documents sent to Gregoire
    [CompassIO_Project.PrjPcb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]
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2018-11-27 feat: Fix parser BT
    [main.c]
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2018-11-27 feat: Add Servo Motor Set Angle
    [Bill of Materials.xls, PCB_Project_TP.PrjPcb]
2018-11-27 feat: Work on GPS error live parse
    [main.c, types.h, uart.c]
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2018-11-27 feat: Problem ms interrupt timer uart/mag
    [mag.c, main.c, uart.c]
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2018-11-27 feat: Reorganise + implement offset mag (doesn't work yet)
    [mag.c, main.c, types.h]
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2018-11-27 feat: Bluetooth OK - Need to check/handle lat/long sorage + Crash fixed --> __ISR(..., IPL2SRS) -> __ISR(..., IPL1)
    [main.c, types.h]
2018-11-27 Fixing issues : crash on power off, button rebound
    [main.c]
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2018-11-27 Resolving issues with flash memory
    [main.c, types.h]
2018-11-27 Solving UART2 issue
2018-11-27 Trying to resolve GPS issues
    [lib.c, main.c, types.h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]
2018-11-27 Solving UART2 issues
2018-11-27 Trying to resolve issues on GPS Parsing
    [main.c]
2018-11-27 Trying to resolve GPS
    [lib.c, main.c, types.h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]
2018-11-27 Resolving issue on BT + trying to resolve get_direction issue
    [main.c, types.h, uart.c]
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
